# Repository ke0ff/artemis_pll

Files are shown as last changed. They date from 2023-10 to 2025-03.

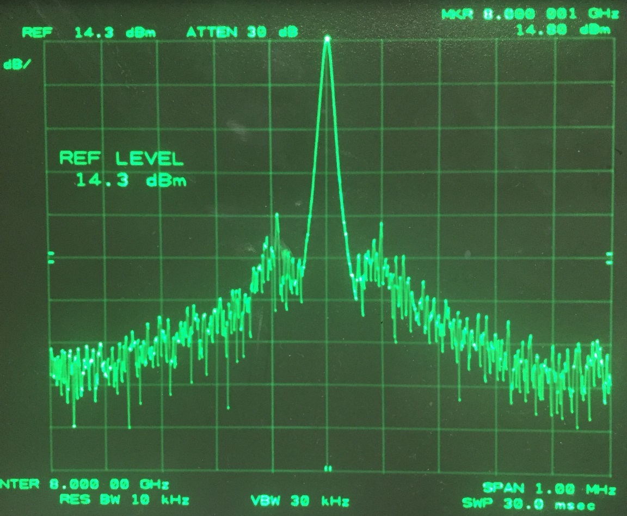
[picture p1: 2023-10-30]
Artemis_8GHz.JPG

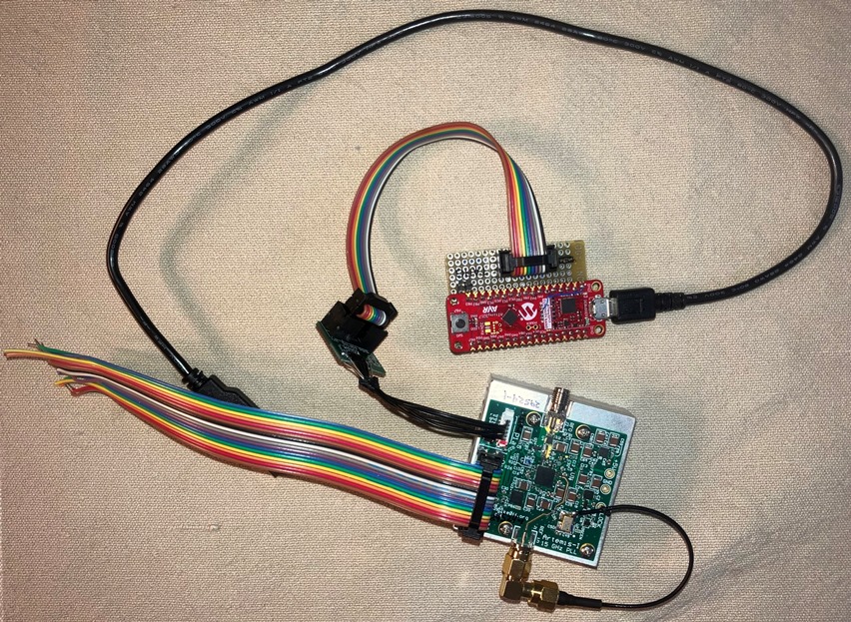
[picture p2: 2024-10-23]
Artemis with pgmr.JPG

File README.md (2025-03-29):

# artemis_pll
LMX2594 PLL Synth Project Files (4 GHz to 15 GHz)

Artemis PLL Synthesizer application

The follow-on to the Orion synthesizer.  Artemis uses an LMX2594 (TI) PLL (with integrated VCO) and an ATtiny-3217 to configure the PLL via an SPI interface. Uses a 5-bit channel select logic interface to set a channel (32 max channels, but likely just a handful will be implemented) or can accept serial commands (115200 baud) to set channel using a serial command line format. Currently requires channel data to be previously determined using the TI application software (TICS Pro) and compiled using the Microchip/Atmel code development environment.
Note: While the TI LMX2594 covers 10MHz to 15 GHz, the choice of buffer amplifier limits the available output range to 4 GHz and above.  For applications needing less than 4GHz, use the Orion-I synthesizer.  For applications needing full coverage, a different amplifier design would be needed -- This would likely mean removing/bypassing the existing buffer (not a good idea at RF) or produce a different PCB layout.

Atemis3217.zip holds the initial software project commit as a single zip archive.
Artemis Source holds in-process commits (files changed as individual source files).

Software for this project was developed with the AtmelStudio IDE.  Microchip has rebranded this as the MicrochipStudio For AVR devices.  Visit https://www.microchip.com/en-us/tools-resources/develop/microchip-studio to install the current version of this toolchain.  To Build the SW project, first unzip "Artemis3217.zip".  Next, copy files (if any) from "Artemis Source" to their respective locations inside the Atmel project folder structure (this might require some trial and error to find where the files belong).
Lastly, build the project and program the target device.  Note: if the "Artemis Source" folder is empty, there are no files to copy.

See my Programming Guide (https://ke0ff.github.io/Orion/silabspgm.pdf) for details on how to build a UPDI programmer using a CurosityNano-3217 development board.

TICSPro software (https://www.ti.com/tool/TICSPRO-SW) from TI is the best choice for configuring the PLL and capturing the resulting register settings (there are 112, 16b registers, 79 of which are required for basic Artemis operation).

These supporting files are also included:</br>
ArtemisHW.zip holds the CircuitStudio schematic and PCB files</br>
Artemis_schem.pdf is the schematic in pdf format</br>
Artemis_BOM.xlsx is the Bill Of Materials</br>

V0.3 SW is now in alpha-test:</br>
Features 8 channels with download and FLASH programming capability to allow stand-alone channel maintenance.  Temporary download channel can be sent to PLL for test, or programmed to a FLASH channel.

Temperature sensor calibration is now in User EEPROM allowing stand-alone calibraton that is not disturbed by programming operations.

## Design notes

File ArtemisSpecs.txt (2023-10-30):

Specifications for Artemis-I, 4 GHz - 15 GHz synthesizer
Preliminary, 10/29/2023
Designed by: Joe Haas, KE0FF

PLL: TI LMX2594HAT, 10 MHz - 15 GHz PLL, on-board lock LED indicator
Buffer: PMA2-183LN+, 4-18 GHz, +14dBm IP1
DC Power: +5Vdc, 400mA
	NOTE: Board requires a heatshink/thermal pad solution
REF: Solder-selectable jumper/capacitor
	EXT REF connection: SMA, 0.2 - 2.0 Vpp, 5 MHz (min) - 1400 MHz (max)
	INT REF: 25MHz, EXC-TX053-S3-33-250-BN-TR
TTL UART cmd I/O: 3.3V logic, 115200 baud, n81
Control MCU: ATTINY-3217 (uses Atmel 1-wire UPDI programming connection)

RF Out (preliminary), SMA:
4GHz	+14dBm
8GHz	+14dBm	phase noise = -80 dBm/Hz
11GHz	+12dBm
13GHz	+10dBm
PLL programming allows for adjustment of the output level in 32 steps.
The data above depicts the maximum setting for each frequency listed

Physical:
Board dimensions: 1.740" x 1.875" x 0.355" (excluding SMA & P2 connectors)
MTG holes, #2 DIA, 4 places
P2 pinout
 1: +12Vin (not used)
 2: GND
 3: Debug RXD, 3.3V TTL serial, input to Artemis board
 4: +5V in
 5: Bebug TXD, 3.3V TTL serial, output from Artemis board
 6: GND
 7: /DISABLE (GND = disable output)
 8: FSEL0
 9: FSEL1
10: FSEL2
11: FSEL3
12: FSEL4
13: N/C
14: UPDI programming connection for ATTINY MCU
15: +3.3V output (10 mA, max)
16: GND

FSEL[4:0] form the channel selection vector allowing up to 32 different
frequency selections from a single master PLL register suite.

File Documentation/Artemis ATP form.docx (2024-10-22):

Artemis Acceptance Test Procedure

Date: _____ / ______ / 20___ S/N: ___________________ SW Version: _______

Test Operator: ______________ Power +5Vin: _______________ Vdc (measure at PCB TP)

1) UART TX serial test: Observe Power-on banner message. Passes if message is displayed with no garbled characters. P/F: _________

2) UART RX serial test: Issue “?” help command from PC terminal. Passes if help message is displayed with no garbled characters. P/F: _________

3) FSEL Test: Cycle through binary inputs and observe channel display on serial terminal. Passes if all digits are recognized and displayed (after settling). P/F: _________

4) /MUTE Test: cycle /MUTE, and observe channel display on serial terminal. Passes if channel output toggles (muted output less or equal to -40 dBc when unmuted) P/F: _________

5) +3.3V out Test: Measure P2-15 with a DMM. Passes if voltage = 3.3V ±10%.

V(3.3V): ____________ P/F: _________

6) Sideband Test: Set CH2 and observe the output at 11 GHz on a spectrum analyzer (1 MHz span). Verify that any sidebands are ≤-40 dBc. Record strongest sideband. Note: sidebands are considered measurable if they are greater than 3 dB above the noise floor.

(Fc level: ________ dBm) – (SB level: _______ dBm) = _________ dBc

Span: ___________ MHz SB Frequency: Fc± ___________ (MHz) P/F: _________

7) Output level test #1: Set CH1 and observe the output at 8 GHz on a spectrum analyzer. Record the signal level. Passes if output is ≥ +10 dBm & frequency is 8 GHz +/-10KHz.

Level: __________ dBm P/F: _________

8) Output level test #2: Set CH3 and observe the output at 15 GHz on a spectrum analyzer. Record the signal level. Passes if output is ≥ 0 dBm. Level: __________ dBm P/F: _________

Set CH0, passes if 3 GHz level is ≥ +10 dBm Level: __________ dBm P/F: _________

9) Noise Test: Set CH2 and observe the output at 11 GHz on a spectrum analyzer. Center on the peak, set a 100 Khz span and measure the abs. noise level. Passes if NL is better than -78 dBc/Hz at 10KHz offset. Fc level: __________ dBm Noise level: ______________ dBm/Hz

NL (dBc) = {Noise Level} - {Fc level} = ______________ dBc/Hz P/F: _________

10) Load custom channel config and test with custom reference settings. Done: ________

REFERENCE Freq: __________________ Level: ___________________

FSEL 0: ___________________________ FSEL 1: ___________________________

FSEL 2: ___________________________ FSEL 3: ___________________________

Test Operator Signature: ___________________________________________

REV - 10/21/2024

Artemis ATP: Test Setup

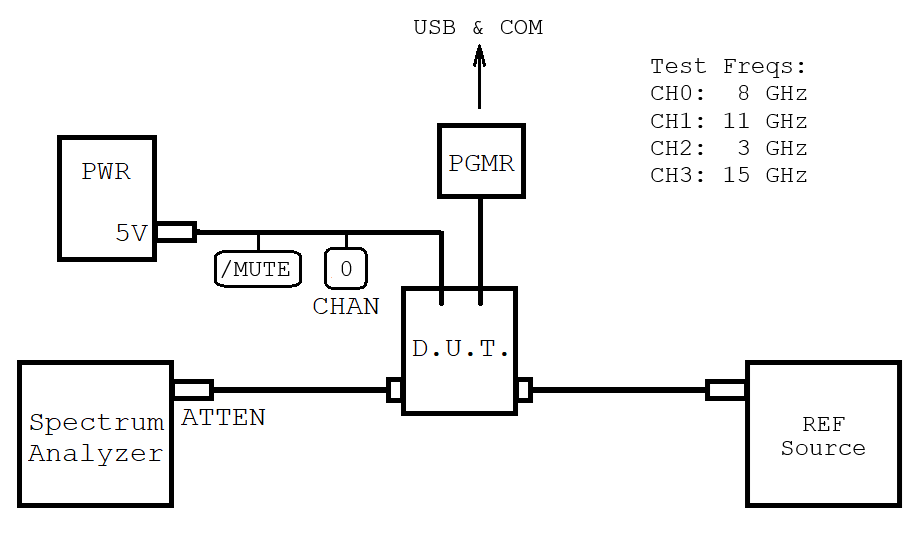
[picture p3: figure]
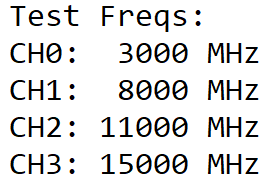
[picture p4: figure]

POWER SUPPLY: ______________________________________________

DMM Model/SN: _______________________________________________

S/A: __________________________________________________________

EXT. ATTEN: ______ dB ATTEN MODEL/SN: ______________________________

D.U.T. RF OUT CABLE: _________________________________________

LOSS AT 2 GHz: ________________ dB LOSS AT 12 GHz: _______________ dB

LOSS AT 8 GHz: _______________ dB LOSS AT 15 GHz: _______________ dB

ATP REF SOURCE: ______________________________________________

LEVEL AT D.U.T. CONNECTOR: ________________ dBm

Date: _____ / ______ / 20___ TEST OPERATOR: ________________________________

REV - 10/21/2024

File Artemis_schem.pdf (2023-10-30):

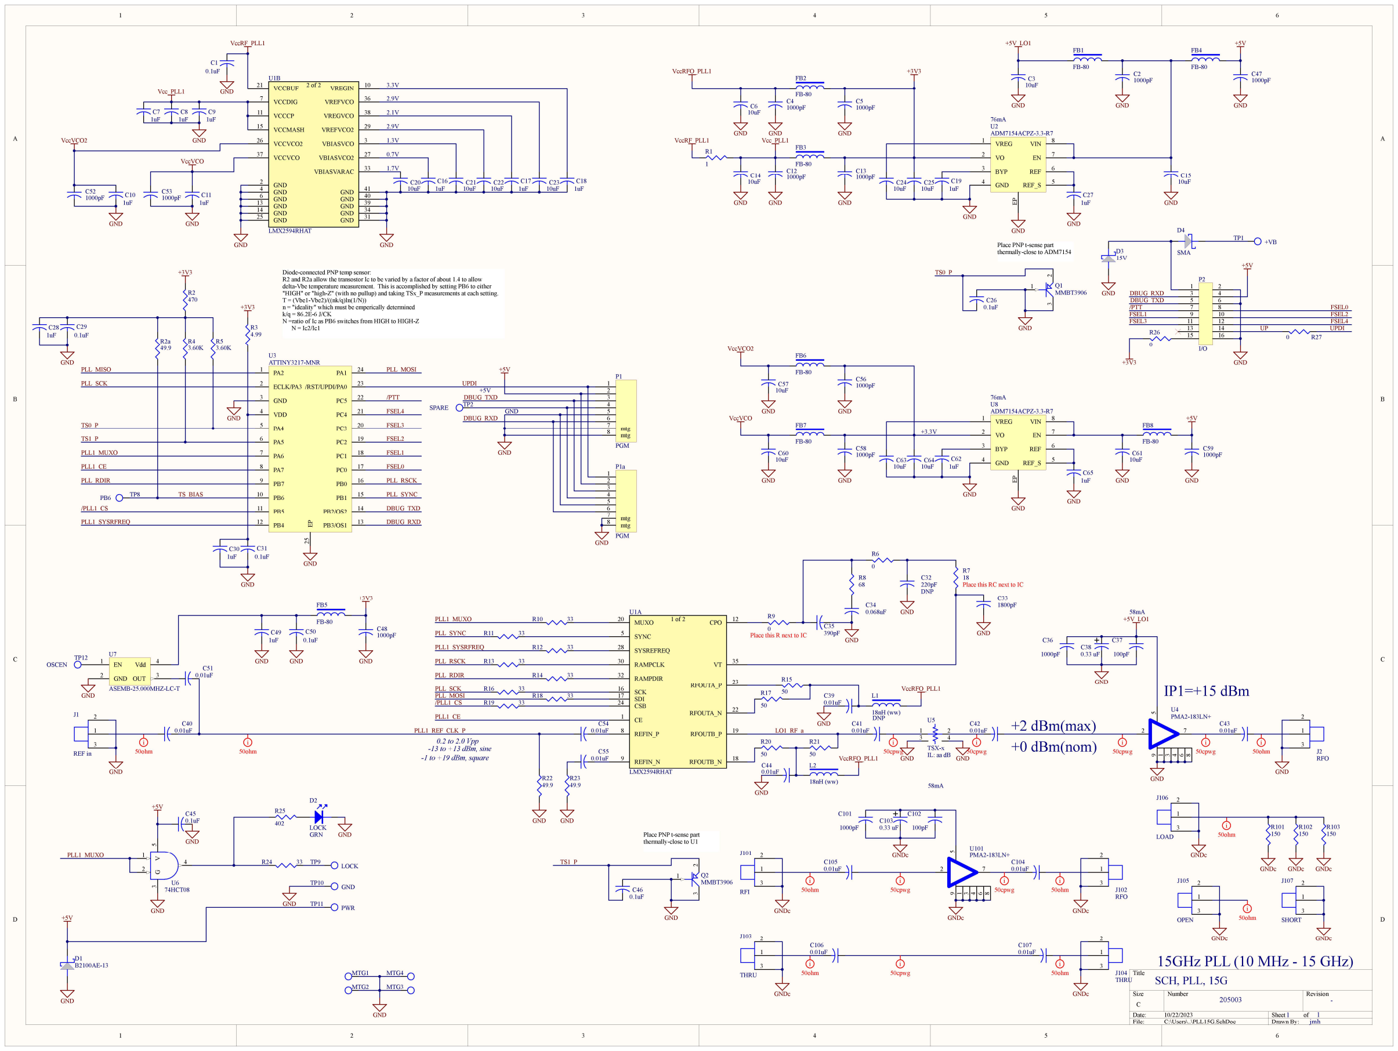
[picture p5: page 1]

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
Title

Size | Number | | Revision
C
Date: | 10/22/2023 | Sheet | of
File: | C:\Users\..\PLL15G.SchDoc | Drawn By:

| | | 1 1

# SCH, PLL, 15G

205003

jmh

VREG 1

VO 2

BYP 3

GND 4 | REF_S | 5
| REF | 6
| EN | 7
VIN | 8 EP

U2
ADM7154ACPZ-3.3-R7

C19
1uF

C25
10uF

C24
10uF
C27
1uF

GND

GND

GND

C13
1000pF

GND

C15
10uF

FB3

FB-80
C12
1000pF

GND

C14
10uF

GND

PLL1_MUXO

PLL1_CE

PLL_MOSI

PLL_SCK

/PLL1_CS

C35
390pF

68

R8 | 18 R7

C34
0.068uF

DNP

C32
220pF

C33
1800pF

GND

GND

Place this R next to IC | GND Place this RC next to IC
R16 | 33
R19 | 33
R18 | 33

49.9

R23

GND

1

R1

Vcc_PLL1

VccRF_PLL1

R10 | 33

0

R6

0

R9

CE 1

CPO | 12
VT | 35

SCK 16
SDI 17
CSB 24

MUXO 20

RFOUTB_N | 18
RFOUTB_P | 19
RFOUTA_P | 23

### 1 of 2

RFOUTA_N 22

SYNC 5

SYSREFREQ 28

RAMPCLK 30

RAMPDIR 32

REFIN_N 9

REFIN_P 8

U1A

LMX2594RHAT

VCCBUF 21

VCCDIG 7

VCCCP 11

VCCMASH 15

VCCVCO2 26

VCCVCO 37

GND 4
GND 6
GND 13
GND 14
GND 25 | GND | 31 GND | 34 GND | 39 GND | 40 GND | 41

### 2 of 2

GND 2

VREGIN | 10
VREFVCO | 36
VREGVCO | 38
VREFVCO2 | 29
VBIASVCO | 3
VBIASVCO2 | 27
VBIASVARAC | 33

U1B

LMX2594RHAT

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
10uF

C21
10uF

C17
1uF

C22
10uF

C18
1uF

C23
10uF

GND

VccRF_PLL1 | Vcc_PLL1

GND

C1
0.1uF

PLL1_REF_CLK_P

### 0.2 to 2.0 Vpp -13 to +13 dBm, sine

50

R21

C41
0.01uF

L2

18nH (ww)

50

R20

C44
0.01uF

GND

C5
1000pF

GND

FB2

FB-80
C4
1000pF

GND

C6
10uF

GND

VccRFO_PLL1

VccRFO_PLL1

50

R15

DNP

L1

18nH (ww)

50

R17 | C39 0.01uF
| GND

VccRFO_PLL1

PLL1_SYSRFREQ

PLL_SYNC | R11 | 33
R12 | 33

PLL_RDIR

PLL_RSCK | R13 | 33
R14 | 33

C2
1000pF

GND

FB1

FB-80
C3
10uF

GND

+5V_LO1

# 15GHz PLL (10 MHz - 15 GHz)

### -1 to +19 dBm, square

LO1_RF_a

GND

C37

100pF

GND

58mA
+5V_LO1

C36

1000pF

C38

### 0.33 uF

76mA

i
50cpwg

i
50cpwg

# +2 dBm(max)

# IP1=+15 dBm

2

1

3
J2
RFO

D1
B2100AE-13

2 7 ⁵ 9

1

3

4

6

8

U4
PMA2-183LN+

# +0 dBm(nom)

VDD 4

PA4 5

PA5 6

PA6 7

PA7 8

PB7 9

PB6 10

PB3/OS1 | 13
PB2/OS2 | 14
PB1 | 15

GND 3

ECLK/PA3 2

PA2 1 | PA1 | 24
| /RST/UPDI/PA0 | 23
PC3 | 20
PC2 | 19
PC1 | 18
PC0 | 17
PB0 | 16 EP 25

PB5 11

PB4 12

PC4 | 21
PC5 | 22

U3
ATTINY3217-MNR

1 2

IL: aa dB

3 4

U5

TSX-x
GND | GND

C43
0.01uF

C42
0.01uF

+3V3

+3V3

C30
1uF

C31
0.1uF

GND

4.99

R3

GND

PLL1_MUXO

PLL1_CE

PLL_MOSI

PLL_SCK

/PLL1_CS

PLL1_SYSRFREQ

PLL_SYNC

PLL_RDIR | PLL_RSCK

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
mtg 7
mtg 8

P1

PGM

+5V

DBUG_TXD

DBUG_RXD

PLL_MISO

TS0_P

TS1_P

C46
0.1uF

1 2 3
Q2
MMBT3906

GND

Place PNP t-sense part
thermally-close to U1

TS1_P

3.60K

R5

GND

470

R2

3.60K

R4

+3V3

C28
1uF

C29
0.1uF

GND

C26
0.1uF

1 2 3
Q1
MMBT3906

GND

Place PNP t-sense part
thermally-close to ADM7154

TS0_P

TP8 PB6

2

1

3

J1

REF in

C40
0.01uF

49.9

R22

GND

GND | GND
GND | GND

i
50ohm

i
50ohm

i
50ohm

i
50cpwg

i
50cpwg
TP11 | PWR
TP10 | GND
TP9 | LOCK

PLL1_MUXO

GND

1

2

### 4 V

### 5 G

3

U6
74HCT08
R24 | 33

GND

1.7V

0.7V

1.3V

2.9V

2.1V

2.9V

3.3V

+5V

GND

+5V

GND

+5V
C45
0.1uF

GND

TP2 SPARE

C47
1000pF

GND

FB4

FB-80

EN 1

GND 2 | OUT | 3
| Vdd | 4

U7

ASEMB-25.000MHZ-LC-T
GND

TP12
OSCEN | C51 0.01uF

C48
1000pF

GND

FB5

FB-80

GND | GND

C49
1uF

C50
0.1uF

+3V3

VREG 1

VO 2

BYP 3

GND 4 | REF_S | 5
| REF | 6
| EN | 7
VIN | 8 EP

U8
ADM7154ACPZ-3.3-R7

C62
1uF

C64
10uF

C63
10uF
C65
1uF

GND

GND

GND

C58
1000pF

GND

C61
10uF

FB7

FB-80
C60
10uF

GND

VccVCO

C56
1000pF

GND

FB6

FB-80
C57
10uF

GND

VccVCO2

76mA

+5V

GND

C59
1000pF

GND

FB8

FB-80

C11
1uF

GND

C10
1uF

GND

C53
1000pF

C52
1000pF

VccVCO

VccVCO2

+3.3V

402

R25

GRN

D2

LOCK
GND

DBUG_TXD

DBUG_RXD

UPDI

1
2
3
4
5
6
mtg 7
mtg 8

P1a

PGM
GND

MTG3

GND

MTG4

MTG2

MTG1

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
/PTT
FSEL1
FSEL3

FSEL0
FSEL2

GND

+5V

FSEL1

FSEL3

FSEL0

FSEL2

D3
15V

GND

D4

SMA

TP1
+VB

DBUG_TXD

DBUG_RXD

+3V3

FSEL4

0

R26

/PTT

FSEL4

C54
0.01uF

C55
0.01uF

2

1

3

J101

RFI

GNDc

i
50ohm

2

1

3
J102
RFO

C104

2 | 7 | 0.01uF ⁵ 9

1

3

4

6

8

U101
PMA2-183LN+

i
50ohm

C102

100pF

58mA

C101

1000pF

C103

### 0.33 uF

GNDc

GNDc
GNDc

i
50cpwg

2

1

3

J103

THRU

GNDc

i
50ohm

2

1

3
J104
THRU

C107
0.01uF
i
50ohm

GNDc

i
50cpwg

C105
0.01uF

C106
0.01uF

i
50cpwg

2

1

3

J105

OPEN

GNDc

i
50ohm

2

1

3

J107

SHORT

GNDc

2

1

3

J106

LOAD

GNDc

i
50ohm

GNDc

150

R101

GNDc

150

R102

GNDc

150

R103

UPDI

### 0 R27

UP

49.9

R2a

Diode-connected PNP temp sensor:
R2 and R2a allow the transostor Ic to be varied by a factor of about 1.4 to allow delta-Vbe temperature measurement. This is accomplished by setting PB6 to either "HIGH" or "high-Z" (with no pullup) and taking TSx_P measurements at each setting. T = (Vbe1-Vbe2)/((nk/q)ln(1/N))
n = "ideality" which must be emperically determined
k/q = 86.2E-6 J/CK
N =ratio of Ic as PB6 switches from HIGH to HIGH-Z N = Ic2/Ic1

TS_BIAS

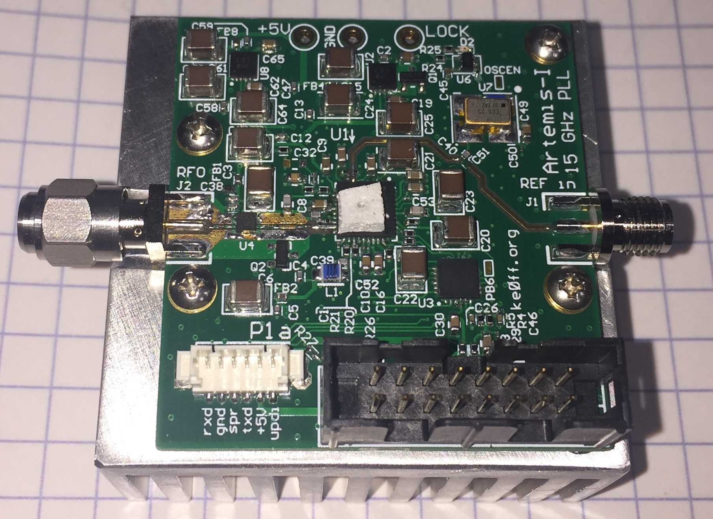
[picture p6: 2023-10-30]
Artemis-I.JPG

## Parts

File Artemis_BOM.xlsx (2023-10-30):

Qty | Designator | Description | MFR | MPN | Cost | Cost ea.
4 | C1, C29, C31, C50 | CAP, MLCC, X5R, 0201, 25V, 10%, 0.1uF | Taiyo Yuden | GMK063BJ104KP-F | $0.20 | 0.050
10 | C2, C4, C5, C12, C13, C47, C48, C56, C58, C59 | CAP, MLCC, C0G, 0402, 100V, 10%, 1000pF | Kemet | C0402C102J1GEC7411 | $0.59 | 0.059
3 | C26, C45, C46 | CAP, MLCC, X5R, 0402, 25V, 10%, 0.1uF | Murata | GRM155R71H104KE14D | $0.04 | 0.014
2 | C27, C65 | CAP, MLCC, X7R, 0603, 50V, 10%, 1uF | Taiyo Yuden | UMK107AB7105MA-T | $0.37 | 0.186
15 | C3, C6, C14, C15, C20, C21, C22, C23, C24, C25, C57, C60, C61, C63, C64 | CAP, MLCC, X7R, 1210, 50V, 10%, 10uF | Kemet | C1210C106K5RACTU | $7.98 | 0.532
1 | C33 | CAP, MLCC, C0G, 0603, 100V, 10%, 1800pF | Murata | GRM1885C2A182JA01D | $0.04 | 0.038
1 | C34 | CAP, MLCC, C0G, 0603, 50V, 10%, 0.068uF | TDK | VJ0603Y683KXACW1BC | $0.03 | 0.028
1 | C35 | CAP, MLCC, C0G, 0603, 50V, 10%, 390pF | TDK | C1608C0G2A391K080AA | $0.04 | 0.045
1 | C36 | CAP, MLCC, C0G, 0402, 50V, 5%, 1000pF | Murata | GRM1555C1H102FA01D | $0.07 | 0.066
1 | C37 | CAP, MLCC, C0G, 0402, 50V, 5%, 100pF | Murata | GRM1555C1H101JA01J | $0.01 | 0.013
1 | C38 | CAP, TANT, SMD, 0402, 0.33uF, 20V | ROHM Semi | TCTU1D334M8R | $0.33 | 0.331
3 | C39, C44, C51 | CAP, MLCC, C0G, 0402, 16V, 10%, 10000pF | Murata | GRM1555CYA103GE01D | $0.20 | 0.068
3 | C41, C42, C43 | CAP, MLCC, C0G, 0201, 16V, 10%, 0.1uF | Passives Plus | 0201BB104KW160 | $3.71 | 1.236
2 | C54, C55 | CAP, MLCC, C0G, 0201, 16V, 10%, 10000pF | Taiyo Yuden | MSASU063SB5103KFNA01 | $0.14 | 0.071
2 | C52, C53 | CAP, MLCC, C0G, 0201, 100V, 10%, 1000pF | Murata | GRM0335C1H102GE01D | $0.04 | 0.019
13 | C7, C8, C9, C10, C11, C16, C17, C18, C19, C28, C30, C49, C62 | CAP, MLCC, X7R, 0603, 50V, 10%, 1uF | Taiyo Yuden | MSASU168AB7105KTNA01 | $2.27 | 0.175
1 | D1 | DIO, 50V, SHTKY, SMA | MCC | SS2150-LTP | $0.27 | 0.273
1 | D2 | LED, 0402, GRN | Kingbright | APG1005CGC-T | $0.24 | 0.240
1 | D3 | DIO, TVS, 15V, 500W | MCC | SMAJ16A-TP | $0.27 | 0.267
1 | D4 | DIO, TVS, 5V, 500W, DIODE | Yageo | P4SMA6.8A/TR13 | $0.26 | 0.260
8 | FB1, FB2, FB3, FB4, FB5, FB6, FB7, FB8 | Bead, Ferrite, SMD, 80 ohm | Laird | MI0402K121R-10 | $0.98 | 0.123
2 | J1, J2 | CONN, SMA, EDGE | TE Connectivity | CONSMA003.062 | $8.70 | 4.350
2 | L1, L2 | IND, CHP, WW, 3.3nH, 0805 | Kyocera | L08053R3CEWTR | $1.41 | 0.707
0 | P1 or P1a | CON, PICBLD, 1.25MM, 6POS (optional) | Molex | 53398-0671 | $0.00 | 0.715
1 | P2 | CON, DIP, 16 POS | 3M | D2516-6002-AR | $2.02 | 2.020
1 | P2-mate | CON, IDC, 16 POS | 3M | D89116-0031HK | $1.74 | 1.740
6 | P2-cable (per inch) | CBL, RBN, 16 POS | 3M | 3801/16 | $0.40 | 0.067
2 | Q1, Q2 | TRAN, PNP, 40V, 100mA, 4.7K bias | OnSemi | MMUN2132LT1G | $0.18 | 0.091
1 | R1 | RES, CHP, 0402, 1%, 100ppm/C, 1 | Vishay/Dale | RCC04021R00FKED | $0.05 | 0.048
9 | R10, R11, R12, R13, R14, R16, R18, R19, R24 | RES, CHP, 0402, 1%, 33 | Yageo | RC0402FR-0733RL | $0.08 | 0.009
2 | R15, R17 | RES, CHP, RF, 0402, 0.1%, 50 | Vishay/Dale | FC0402E50R0BST1 | $4.34 | 2.170
1 | R2 | RES, CHP, 0402, 1%, 470 | Yageo | RC0402FR-07470RL | $0.01 | 0.009
4 | R20, R21, R22, R23 | RES, CHP, 0201, 1%, 49.9 | Yageo | RC0201FR-0749R9L | $0.04 | 0.009
1 | R25 | RES, CHP, 0402, 1%, 402 | Yageo | RC0402FR-07402RL | $0.01 | 0.009
1 | R2a | RES, CHP, 0402, 1%, 49.9 | Yageo | RC0402FR-0749R9L | $0.01 | 0.009
1 | R3 | RES, CHP, 0402, 1%, 4.99 | Yageo | RC0402FR-074R99L | $0.01 | 0.009
2 | R4, R5 | RES, CHP, 0402, 1%, 3.60K | Yageo | RC0402FR-073K6L | $0.02 | 0.009
4 | R6, R9, R26, R27 | RES, CHP, 0402, 1%, 0 | Yageo | RC0402FR-070RL | $0.04 | 0.009
1 | R7 | RES, CHP, 0402, 1%, 18 | Yageo | RC0402FR-0718RL | $0.01 | 0.009
1 | R8 | RES, CHP, 0402, 1%, 68 | Yageo | RC0402FR-0768RL | $0.01 | 0.009
1 | U1 | IC, PLL, w/VCO, 7.3-15000 MHz, 300MHz REF | TI | LMX2594RHAT | $84.21 | 84.210
2 | U2, U8 | IC, VREG, ULN, 3.3V | Analog Devices | ADM7154ACPZ-3.3-R7 | $13.92 | 6.960
1 | U3 | IC, MCU, SFF, 8b, 32Kb, 20MHz | MicroChip | ATTINY3217-MNR | $1.25 | 1.250
1 | U4 | MMIC, AMP, E-PHEMT | Mini Circuits | PMA2-183LN+ | $38.98 | 38.980
1 | U6 | IC,GATE,2IN,AND,SNGL, | TI | SN74AHC1G08DCKR | $0.24 | 0.245
ALT | U7 | IC, OSC, SMD, W_EN | Abracon | ASEMB-25.000MHZ-LC-T |  | 2.840
1 | U7 | IC, OSC, SMD, W_EN | ECS | ECS-TXO53-S3-33-250-BN-TR | $9.86 | 9.860
1 | PCB | PCB, Artemis-I, Rev - | ANY | Artemis-I | $12.00 | 12.000
1 | THP1 | Pad, Thermal, 1”x1” | Laird | A15959-07 | $0.76 | 0.762
1 | HS1 | Heat Sink, 2”x2”, 5W – heatsinkonline.com | heatsinkonline.com | 253AS | $2.68 | 2.680
1 | MACHINE-OP | Machining for HS1, LOT | ANY | PER-DWG | $20.00 | 20.000
1 | PCB-ASSY | ASSEMBLY COSTS, PCB | ANY | PER-DWG | $20.00 | 20.000
1 | MISC | MISC FREIGHT COSTS/TAXES | N/A |  | $25.24 | 25.239
 |  |  |  |  | ==========
 |  |  |  | Total cost => | $266.31
DO NOT POPULATE:
1 | C32 | CAP, MLCC, C0G, 0402, ?V, 10%, ?pF | ? | ?
1 | C40 | CAP, MLCC, C0G, 0402, 16V, 10%, 10000pF | Murata | GRM1555CYA103GE01D
1 | U5 | ATTEN, FXD, SMD, 1W | Smiths Interconnect | TSXaa.00

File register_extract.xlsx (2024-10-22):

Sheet: Output
Artemis Channel Formatting Spreadsheet
Copy data from TICSPro export files into the respective channel tabs. Copy and paste all of the file data.
Be sure to align the pasted data to cell A1 in each channel tab.
Once all of the channels are configured, copy the “A” and “B” columns into the “channels.c” source file in the ATTINY project
Compile and load the program onto the Artemis board.
Note: All channels need to have valid data even if they are not going to be used.
{ | // channel 0 | <<== Copy from here to the last row
0x0180,
0x0003,
0x0000,
0x000C,
0x0800,
0x0000,
0x003F,
0x0001,
0x0081,
0xC350,
0x0000,
0x03E8,
0x0000,
0x01F4,
0x0000,
0x1388,
0x0000,
0x0322,
0x00A8,
0x0000,
0x0001,
0x9001,
0x0020,
0x0000,
0x0000,
0x0000,
0x0000,
0x0820,
0x0080,
0x0000,
0x4180,
0x0300,
0x0300,
0x07FC,
0xC0DF,
0x1FA3,
0x0000,
0x0000,
0x0000,
0x0000,
0x03E8,
0x0000,
0x0404,
0x0240,
0x0004,
0x0000,
0x1E21,
0x0393,
0x43EC,
0x318C,
0x318C,
0x0488,
0x0002,
0x0DB0,
0x0C2B,
0x071A,
0x007C,
0x0001,
0x0401,
0xE048,
0x27B7,
0x0064,
0x012C,
0x0080,
0x064F,
0x1E70,
0x4000,
0x5001,
0x0018,
0x10D8,
0x1604,
0x2000,
0x40B2,
0xC802,
0x00C8,
0x0A43,
0x0642,
0x0500,
0x0808,
0x241C
},
{ | // channel 1
0x0180,
0x0003,
0x0000,
0x000C,
0x0800,
0x0000,
0x003F,
0x0001,
0x0081,
0xC350,
0x0000,
0x03E8,
0x0000,
0x01F4,
0x0000,
0x1388,
0x0000,
0x0322,
0x00A8,
0x0000,
0x0001,
0x9001,
0x0020,
0x0000,
0x0000,
0x0000,
0x0000,
0x0820,
0x0080,
0x0000,
0x4180,
0x0300,
0x0300,
0x07FC,
0xC0DF,
0x1FA3,
0x0000,
0x0000,
0x0000,
0x0000,
0x03E8,
0x0000,
0x0404,
0x0240,
0x0004,
0x0000,
0x1E21,
0x0393,
0x43EC,
0x318C,
0x318C,
0x0488,
0x0002,
0x0DB0,
0x0C2B,
0x071A,
0x007C,
0x0001,
0x0401,
0xE048,
0x27B7,
0x0064,
0x012C,
0x0080,
0x064F,
0x1E70,
0x4000,
0x5001,
0x0018,
0x10D8,
0x1604,
0x2000,
0x40B2,
0xC802,
0x00C8,
0x0A43,
0x0642,
0x0500,
0x0808,
0x241C
},
{ | // channel 2
0x0180,
0x0003,
0x0000,
0x000C,
0x0800,
0x0000,
0x003F,
0x0001,
0x0081,
0xC350,
0x0000,
0x03E8,
0x0000,
0x01F4,
0x0000,
0x1388,
0x0000,
0x0322,
0x00A8,
0x0000,
0x0001,
0x9001,
0x0020,
0x0000,
0x0000,
0x0000,
0x0000,
0x0820,
0x0080,
0x0000,
0x4180,
0x0300,
0x0300,
0x07FC,
0xC0DF,
0x1FA3,
0x0000,
0x0000,
0x0000,
0x0000,
0x03E8,
0x0000,
0x0404,
0x0240,
0x0004,
0x0000,
0x1E21,
0x0393,
0x43EC,
0x318C,
0x318C,
0x0488,
0x0002,
0x0DB0,
0x0C2B,
0x071A,
0x007C,
0x0001,
0x0401,
0xE048,
0x27B7,
0x0064,
0x012C,
0x0080,
0x064F,
0x1E70,
0x4000,
0x5001,
0x0018,
0x10D8,
0x1604,
0x2000,
0x40B2,
0xC802,
0x00C8,
0x0A43,
0x0642,
0x0500,
0x0808,
0x241C
},
{ | // channel 3
0x0180,
0x0003,
0x0000,
0x000C,
0x0800,
0x0000,
0x003F,
0x0001,
0x0081,
0xC350,
0x0000,
0x03E8,
0x0000,
0x01F4,
0x0000,
0x1388,
0x0000,
0x0322,
0x00A8,
0x0000,
0x0001,
0x9001,
0x0020,
0x0000,
0x0000,
0x0000,
0x0000,
0x0820,
0x0080,
0x0000,
0x4180,
0x0300,
0x0300,
0x07FC,
0xC0DF,
0x1FA3,
0x0000,
0x0000,
0x0000,
0x0000,
0x03E8,
0x0000,
0x0404,
0x0240,
0x0004,
0x0000,
0x1E21,
0x0393,
0x43EC,
0x318C,
0x318C,
0x0488,
0x0002,
0x0DB0,
0x0C2B,
0x071A,
0x007C,
0x0001,
0x0401,
0xE048,
0x27B7,
0x0064,
0x012C,
0x0080,
0x064F,
0x1E70,
0x4000,
0x5001,
0x0018,
0x10D8,
0x1604,
0x2000,
0x40B2,
0xC802,
0x00C8,
0x0A43,
0x0642,
0x0500,
0x0808,
0x241C
}
}; |  | <<== This is the last row
///////////////////////////////////////////////////////////////////////////////////////////////////////

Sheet: CH_0
R112 | 0x700000 |  | <<== Insert channel data at cell A1
R111 | 0x6F0000
R110 | 0x6E0000
R109 | 0x6D0000
R108 | 0x6C0000
R107 | 0x6B0000
R106 | 0x6A0000
R105 | 0x690021
R104 | 0x680000
R103 | 0x670000
R102 | 0x663B00
R101 | 0x650011
R100 | 0x640000
R99 | 0x630000
R98 | 0x621400
R97 | 0x610888
R96 | 0x600000
R95 | 0x5F0000
R94 | 0x5E0000
R93 | 0x5D0000
R92 | 0x5C0000
R91 | 0x5B0000
R90 | 0x5A0000
R89 | 0x590000
R88 | 0x580000
R87 | 0x570000
R86 | 0x560001
R85 | 0x550000
R84 | 0x540001
R83 | 0x53FFFF
R82 | 0x52FFFF
R81 | 0x510000
R80 | 0x500000
R79 | 0x4F0180 | 0x0180,
R78 | 0x4E0003 | 0x0003,
R77 | 0x4D0000 | 0x0000,
R76 | 0x4C000C | 0x000C,
R75 | 0x4B0800 | 0x0800,
R74 | 0x4A0000 | 0x0000,
R73 | 0x49003F | 0x003F,
R72 | 0x480001 | 0x0001,
R71 | 0x470081 | 0x0081,
R70 | 0x46C350 | 0xC350,
R69 | 0x450000 | 0x0000,
R68 | 0x4403E8 | 0x03E8,
R67 | 0x430000 | 0x0000,
R66 | 0x4201F4 | 0x01F4,
R65 | 0x410000 | 0x0000,
R64 | 0x401388 | 0x1388,
R63 | 0x3F0000 | 0x0000,
R62 | 0x3E0322 | 0x0322,
R61 | 0x3D00A8 | 0x00A8,
R60 | 0x3C0000 | 0x0000,
R59 | 0x3B0001 | 0x0001,
R58 | 0x3A9001 | 0x9001,
R57 | 0x390020 | 0x0020,
R56 | 0x380000 | 0x0000,
R55 | 0x370000 | 0x0000,
R54 | 0x360000 | 0x0000,
R53 | 0x350000 | 0x0000,
R52 | 0x340820 | 0x0820,
R51 | 0x330080 | 0x0080,
R50 | 0x320000 | 0x0000,
R49 | 0x314180 | 0x4180,
R48 | 0x300300 | 0x0300,
R47 | 0x2F0300 | 0x0300,
R46 | 0x2E07FC | 0x07FC,
R45 | 0x2DC0DF | 0xC0DF,
R44 | 0x2C1FA3 | 0x1FA3,
R43 | 0x2B0000 | 0x0000,
R42 | 0x2A0000 | 0x0000,
R41 | 0x290000 | 0x0000,
R40 | 0x280000 | 0x0000,
R39 | 0x2703E8 | 0x03E8,
R38 | 0x260000 | 0x0000,
R37 | 0x250404 | 0x0404,
R36 | 0x240240 | 0x0240,
R35 | 0x230004 | 0x0004,
R34 | 0x220000 | 0x0000,
R33 | 0x211E21 | 0x1E21,
R32 | 0x200393 | 0x0393,
R31 | 0x1F43EC | 0x43EC,
R30 | 0x1E318C | 0x318C,
R29 | 0x1D318C | 0x318C,
R28 | 0x1C0488 | 0x0488,
R27 | 0x1B0002 | 0x0002,
R26 | 0x1A0DB0 | 0x0DB0,
R25 | 0x190C2B | 0x0C2B,
R24 | 0x18071A | 0x071A,
R23 | 0x17007C | 0x007C,
R22 | 0x160001 | 0x0001,
R21 | 0x150401 | 0x0401,
R20 | 0x14E048 | 0xE048,
R19 | 0x1327B7 | 0x27B7,
R18 | 0x120064 | 0x0064,
R17 | 0x11012C | 0x012C,
R16 | 0x100080 | 0x0080,
R15 | 0x0F064F | 0x064F,
R14 | 0x0E1E70 | 0x1E70,
R13 | 0x0D4000 | 0x4000,
R12 | 0x0C5001 | 0x5001,
R11 | 0x0B0018 | 0x0018,
R10 | 0x0A10D8 | 0x10D8,
R9 | 0x091604 | 0x1604,
R8 | 0x082000 | 0x2000,
R7 | 0x0740B2 | 0x40B2,
R6 | 0x06C802 | 0xC802,
R5 | 0x0500C8 | 0x00C8,
R4 | 0x040A43 | 0x0A43,
R3 | 0x030642 | 0x0642,
R2 | 0x020500 | 0x0500,
R1 | 0x010808 | 0x0808,
R0 | 0x00241C | 0x241C

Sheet: CH_1
R112 | 0x700000 |  | <<== Insert channel data at cell A1
R111 | 0x6F0000
R110 | 0x6E0000
R109 | 0x6D0000
R108 | 0x6C0000
R107 | 0x6B0000
R106 | 0x6A0000
R105 | 0x690021
R104 | 0x680000
R103 | 0x670000
R102 | 0x663B00
R101 | 0x650011
R100 | 0x640000
R99 | 0x630000
R98 | 0x621400
R97 | 0x610888
R96 | 0x600000
R95 | 0x5F0000
R94 | 0x5E0000
R93 | 0x5D0000
R92 | 0x5C0000
R91 | 0x5B0000
R90 | 0x5A0000
R89 | 0x590000
R88 | 0x580000
R87 | 0x570000
R86 | 0x560001
R85 | 0x550000
R84 | 0x540001
R83 | 0x53FFFF
R82 | 0x52FFFF
R81 | 0x510000
R80 | 0x500000
R79 | 0x4F0180 | 0x0180,
R78 | 0x4E0003 | 0x0003,
R77 | 0x4D0000 | 0x0000,
R76 | 0x4C000C | 0x000C,
R75 | 0x4B0800 | 0x0800,
R74 | 0x4A0000 | 0x0000,
R73 | 0x49003F | 0x003F,
R72 | 0x480001 | 0x0001,
R71 | 0x470081 | 0x0081,
R70 | 0x46C350 | 0xC350,
R69 | 0x450000 | 0x0000,
R68 | 0x4403E8 | 0x03E8,
R67 | 0x430000 | 0x0000,
R66 | 0x4201F4 | 0x01F4,
R65 | 0x410000 | 0x0000,
R64 | 0x401388 | 0x1388,
R63 | 0x3F0000 | 0x0000,
R62 | 0x3E0322 | 0x0322,
R61 | 0x3D00A8 | 0x00A8,
R60 | 0x3C0000 | 0x0000,
R59 | 0x3B0001 | 0x0001,
R58 | 0x3A9001 | 0x9001,
R57 | 0x390020 | 0x0020,
R56 | 0x380000 | 0x0000,
R55 | 0x370000 | 0x0000,
R54 | 0x360000 | 0x0000,
R53 | 0x350000 | 0x0000,
R52 | 0x340820 | 0x0820,
R51 | 0x330080 | 0x0080,
R50 | 0x320000 | 0x0000,
R49 | 0x314180 | 0x4180,
R48 | 0x300300 | 0x0300,
R47 | 0x2F0300 | 0x0300,
R46 | 0x2E07FC | 0x07FC,
R45 | 0x2DC0DF | 0xC0DF,
R44 | 0x2C1FA3 | 0x1FA3,
R43 | 0x2B0000 | 0x0000,
R42 | 0x2A0000 | 0x0000,
R41 | 0x290000 | 0x0000,
R40 | 0x280000 | 0x0000,
R39 | 0x2703E8 | 0x03E8,
R38 | 0x260000 | 0x0000,
R37 | 0x250404 | 0x0404,
R36 | 0x240240 | 0x0240,
R35 | 0x230004 | 0x0004,
R34 | 0x220000 | 0x0000,
R33 | 0x211E21 | 0x1E21,
R32 | 0x200393 | 0x0393,
R31 | 0x1F43EC | 0x43EC,
R30 | 0x1E318C | 0x318C,
R29 | 0x1D318C | 0x318C,
R28 | 0x1C0488 | 0x0488,
R27 | 0x1B0002 | 0x0002,
R26 | 0x1A0DB0 | 0x0DB0,
R25 | 0x190C2B | 0x0C2B,
R24 | 0x18071A | 0x071A,
R23 | 0x17007C | 0x007C,
R22 | 0x160001 | 0x0001,
R21 | 0x150401 | 0x0401,
R20 | 0x14E048 | 0xE048,
R19 | 0x1327B7 | 0x27B7,
R18 | 0x120064 | 0x0064,
R17 | 0x11012C | 0x012C,
R16 | 0x100080 | 0x0080,
R15 | 0x0F064F | 0x064F,
R14 | 0x0E1E70 | 0x1E70,
R13 | 0x0D4000 | 0x4000,
R12 | 0x0C5001 | 0x5001,
R11 | 0x0B0018 | 0x0018,
R10 | 0x0A10D8 | 0x10D8,
R9 | 0x091604 | 0x1604,
R8 | 0x082000 | 0x2000,
R7 | 0x0740B2 | 0x40B2,
R6 | 0x06C802 | 0xC802,
R5 | 0x0500C8 | 0x00C8,
R4 | 0x040A43 | 0x0A43,
R3 | 0x030642 | 0x0642,
R2 | 0x020500 | 0x0500,
R1 | 0x010808 | 0x0808,
R0 | 0x00241C | 0x241C

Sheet: CH_2
R112 | 0x700000 |  | <<== Insert channel data at cell A1
R111 | 0x6F0000
R110 | 0x6E0000
R109 | 0x6D0000
R108 | 0x6C0000
R107 | 0x6B0000
R106 | 0x6A0000
R105 | 0x690021
R104 | 0x680000
R103 | 0x670000
R102 | 0x663B00
R101 | 0x650011
R100 | 0x640000
R99 | 0x630000
R98 | 0x621400
R97 | 0x610888
R96 | 0x600000
R95 | 0x5F0000
R94 | 0x5E0000
R93 | 0x5D0000
R92 | 0x5C0000
R91 | 0x5B0000
R90 | 0x5A0000
R89 | 0x590000
R88 | 0x580000
R87 | 0x570000
R86 | 0x560001
R85 | 0x550000
R84 | 0x540001
R83 | 0x53FFFF
R82 | 0x52FFFF
R81 | 0x510000
R80 | 0x500000
R79 | 0x4F0180 | 0x0180,
R78 | 0x4E0003 | 0x0003,
R77 | 0x4D0000 | 0x0000,
R76 | 0x4C000C | 0x000C,
R75 | 0x4B0800 | 0x0800,
R74 | 0x4A0000 | 0x0000,
R73 | 0x49003F | 0x003F,
R72 | 0x480001 | 0x0001,
R71 | 0x470081 | 0x0081,
R70 | 0x46C350 | 0xC350,
R69 | 0x450000 | 0x0000,
R68 | 0x4403E8 | 0x03E8,
R67 | 0x430000 | 0x0000,
R66 | 0x4201F4 | 0x01F4,
R65 | 0x410000 | 0x0000,
R64 | 0x401388 | 0x1388,
R63 | 0x3F0000 | 0x0000,
R62 | 0x3E0322 | 0x0322,
R61 | 0x3D00A8 | 0x00A8,
R60 | 0x3C0000 | 0x0000,
R59 | 0x3B0001 | 0x0001,
R58 | 0x3A9001 | 0x9001,
R57 | 0x390020 | 0x0020,
R56 | 0x380000 | 0x0000,
R55 | 0x370000 | 0x0000,
R54 | 0x360000 | 0x0000,
R53 | 0x350000 | 0x0000,
R52 | 0x340820 | 0x0820,
R51 | 0x330080 | 0x0080,
R50 | 0x320000 | 0x0000,
R49 | 0x314180 | 0x4180,
R48 | 0x300300 | 0x0300,
R47 | 0x2F0300 | 0x0300,
R46 | 0x2E07FC | 0x07FC,
R45 | 0x2DC0DF | 0xC0DF,
R44 | 0x2C1FA3 | 0x1FA3,
R43 | 0x2B0000 | 0x0000,
R42 | 0x2A0000 | 0x0000,
R41 | 0x290000 | 0x0000,
R40 | 0x280000 | 0x0000,
R39 | 0x2703E8 | 0x03E8,
R38 | 0x260000 | 0x0000,
R37 | 0x250404 | 0x0404,
R36 | 0x240240 | 0x0240,
R35 | 0x230004 | 0x0004,
R34 | 0x220000 | 0x0000,
R33 | 0x211E21 | 0x1E21,
R32 | 0x200393 | 0x0393,
R31 | 0x1F43EC | 0x43EC,
R30 | 0x1E318C | 0x318C,
R29 | 0x1D318C | 0x318C,
R28 | 0x1C0488 | 0x0488,
R27 | 0x1B0002 | 0x0002,
R26 | 0x1A0DB0 | 0x0DB0,
R25 | 0x190C2B | 0x0C2B,
R24 | 0x18071A | 0x071A,
R23 | 0x17007C | 0x007C,
R22 | 0x160001 | 0x0001,
R21 | 0x150401 | 0x0401,
R20 | 0x14E048 | 0xE048,
R19 | 0x1327B7 | 0x27B7,
R18 | 0x120064 | 0x0064,
R17 | 0x11012C | 0x012C,
R16 | 0x100080 | 0x0080,
R15 | 0x0F064F | 0x064F,
R14 | 0x0E1E70 | 0x1E70,
R13 | 0x0D4000 | 0x4000,
R12 | 0x0C5001 | 0x5001,
R11 | 0x0B0018 | 0x0018,
R10 | 0x0A10D8 | 0x10D8,
R9 | 0x091604 | 0x1604,
R8 | 0x082000 | 0x2000,
R7 | 0x0740B2 | 0x40B2,
R6 | 0x06C802 | 0xC802,
R5 | 0x0500C8 | 0x00C8,
R4 | 0x040A43 | 0x0A43,
R3 | 0x030642 | 0x0642,
R2 | 0x020500 | 0x0500,
R1 | 0x010808 | 0x0808,
R0 | 0x00241C | 0x241C

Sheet: CH_3
R112 | 0x700000 |  | <<== Insert channel data at cell A1
R111 | 0x6F0000
R110 | 0x6E0000
R109 | 0x6D0000
R108 | 0x6C0000
R107 | 0x6B0000
R106 | 0x6A0000
R105 | 0x690021
R104 | 0x680000
R103 | 0x670000
R102 | 0x663B00
R101 | 0x650011
R100 | 0x640000
R99 | 0x630000
R98 | 0x621400
R97 | 0x610888
R96 | 0x600000
R95 | 0x5F0000
R94 | 0x5E0000
R93 | 0x5D0000
R92 | 0x5C0000
R91 | 0x5B0000
R90 | 0x5A0000
R89 | 0x590000
R88 | 0x580000
R87 | 0x570000
R86 | 0x560001
R85 | 0x550000
R84 | 0x540001
R83 | 0x53FFFF
R82 | 0x52FFFF
R81 | 0x510000
R80 | 0x500000
R79 | 0x4F0180 | 0x0180,
R78 | 0x4E0003 | 0x0003,
R77 | 0x4D0000 | 0x0000,
R76 | 0x4C000C | 0x000C,
R75 | 0x4B0800 | 0x0800,
R74 | 0x4A0000 | 0x0000,
R73 | 0x49003F | 0x003F,
R72 | 0x480001 | 0x0001,
R71 | 0x470081 | 0x0081,
R70 | 0x46C350 | 0xC350,
R69 | 0x450000 | 0x0000,
R68 | 0x4403E8 | 0x03E8,
R67 | 0x430000 | 0x0000,
R66 | 0x4201F4 | 0x01F4,
R65 | 0x410000 | 0x0000,
R64 | 0x401388 | 0x1388,
R63 | 0x3F0000 | 0x0000,
R62 | 0x3E0322 | 0x0322,
R61 | 0x3D00A8 | 0x00A8,
R60 | 0x3C0000 | 0x0000,
R59 | 0x3B0001 | 0x0001,
R58 | 0x3A9001 | 0x9001,
R57 | 0x390020 | 0x0020,
R56 | 0x380000 | 0x0000,
R55 | 0x370000 | 0x0000,
R54 | 0x360000 | 0x0000,
R53 | 0x350000 | 0x0000,
R52 | 0x340820 | 0x0820,
R51 | 0x330080 | 0x0080,
R50 | 0x320000 | 0x0000,
R49 | 0x314180 | 0x4180,
R48 | 0x300300 | 0x0300,
R47 | 0x2F0300 | 0x0300,
R46 | 0x2E07FC | 0x07FC,
R45 | 0x2DC0DF | 0xC0DF,
R44 | 0x2C1FA3 | 0x1FA3,
R43 | 0x2B0000 | 0x0000,
R42 | 0x2A0000 | 0x0000,
R41 | 0x290000 | 0x0000,
R40 | 0x280000 | 0x0000,
R39 | 0x2703E8 | 0x03E8,
R38 | 0x260000 | 0x0000,
R37 | 0x250404 | 0x0404,
R36 | 0x240240 | 0x0240,
R35 | 0x230004 | 0x0004,
R34 | 0x220000 | 0x0000,
R33 | 0x211E21 | 0x1E21,
R32 | 0x200393 | 0x0393,
R31 | 0x1F43EC | 0x43EC,
R30 | 0x1E318C | 0x318C,
R29 | 0x1D318C | 0x318C,
R28 | 0x1C0488 | 0x0488,
R27 | 0x1B0002 | 0x0002,
R26 | 0x1A0DB0 | 0x0DB0,
R25 | 0x190C2B | 0x0C2B,
R24 | 0x18071A | 0x071A,
R23 | 0x17007C | 0x007C,
R22 | 0x160001 | 0x0001,
R21 | 0x150401 | 0x0401,
R20 | 0x14E048 | 0xE048,
R19 | 0x1327B7 | 0x27B7,
R18 | 0x120064 | 0x0064,
R17 | 0x11012C | 0x012C,
R16 | 0x100080 | 0x0080,
R15 | 0x0F064F | 0x064F,
R14 | 0x0E1E70 | 0x1E70,
R13 | 0x0D4000 | 0x4000,
R12 | 0x0C5001 | 0x5001,
R11 | 0x0B0018 | 0x0018,
R10 | 0x0A10D8 | 0x10D8,
R9 | 0x091604 | 0x1604,
R8 | 0x082000 | 0x2000,
R7 | 0x0740B2 | 0x40B2,
R6 | 0x06C802 | 0xC802,
R5 | 0x0500C8 | 0x00C8,
R4 | 0x040A43 | 0x0A43,
R3 | 0x030642 | 0x0642,
R2 | 0x020500 | 0x0500,
R1 | 0x010808 | 0x0808,
R0 | 0x00241C | 0x241C

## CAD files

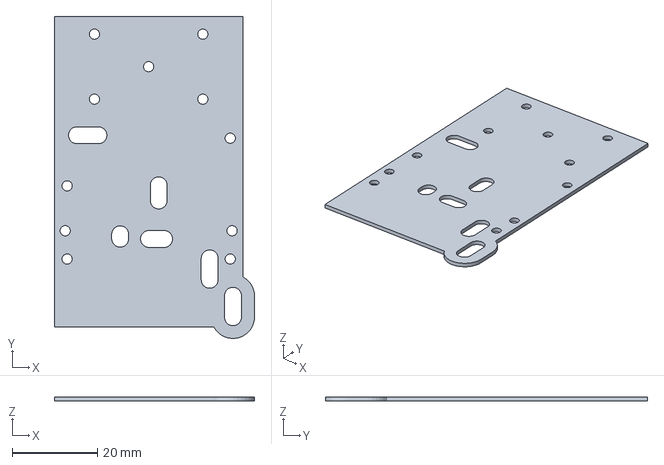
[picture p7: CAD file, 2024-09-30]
Artemis3D/artemis_template.3mf
46.9 x 75.5 x 1.00 mm

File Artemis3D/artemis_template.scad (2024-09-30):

// OpenSCAD 2019.05
// Artemis PCB/heatsink machining template, REV-002
// Joe Haas, KE0FF, 10/28/2023
//
// Rev-002, 09/29/2024
//	Added artefacts for external 5V regulator
//	Adde SMA centerline markers
//
// Rev-001, 10/28/2023
//	initial code

//----------------------------------------------------------------------------------------------------------------------
// User defined parameters.  Modify these to suit a particular application
// NOTE: All data in this file is in mm
//----------------------------------------------------------------------------------------------------------------------
// parametric variables:

thick = 1;
m2m = 25.4/1000; // mils to mm

x0 = 992;
y0 = 700;
hdia = 2.4; //.07*25.4;

width = ((2563-y0)*m2m) + (1000*m2m);
length = (2732-x0)*m2m;

m1x = (1110-x0)*m2m;
m1y = (2000-y0)*m2m;
m2x = m1x;
m2y = (1325-y0)*m2m;
m3x = (2615-x0)*m2m;
m3y = (1325-y0)*m2m;
m4x = m3x;
m4y = (2440-y0)*m2m;
d1x = (1299.5-x0)*m2m;
d1y = (2467-y0)*m2m;
d3x = (2640-x0)*m2m;
d3y = (887-y0)*m2m;
d4x = (2425-x0)*m2m;
d4y = (1232.5-y0)*m2m;
l2x = (1599-x0)*m2m;
l2y = (1533-y0)*m2m;
c60x = (1955-x0)*m2m;
c60y = (1935-y0)*m2m;
c57x = (1935-x0)*m2m;
c57y = (1510-y0)*m2m;
smay = 886*m2m;

genx = 500*m2m;
geny = 300*m2m;

////////////////////////////////////////////////////////////////////////////////

template();
//elipse();

////////////////////////////////////////////////////////////////////////////////


//
//
//**************************************************
				//****************\\
				//    modules     \\
				//    follow      \\
				//****************\\
//**************************************************
//
//
///////////////
// template

module template(){
	difference(){
		// main shape
		union(){
			cube([length,width,thick]);
			// d3 overhang
			translate([d3x,d3y,0]) rotate([0,0,90]) elipse(ww=400*m2m, ll=15, tt=1);
			// d1 overhang
			translate([d1x,d1y,0]) rotate([0,0,0]) elipse(ww=400*m2m, ll=15, tt=1);
		}
		// mtg holes
		translate([m1x,m1y,-1]) cylinder(r=hdia/2, h=3*thick, $fn=32);
		translate([m2x,m2y,-1]) cylinder(r=hdia/2, h=3*thick, $fn=32);
		translate([m3x,m3y,-1]) cylinder(r=hdia/2, h=3*thick, $fn=32);
		translate([m4x,m4y,-1]) cylinder(r=hdia/2, h=3*thick, $fn=32);
		// VREG mtg
		translate([length/2,2400*m2m,-1]) cylinder(r=hdia/2, h=3*thick, $fn=32);
		// reg-module generic mtg
		translate([(length/2)-genx,(2400*m2m)-geny,-1]) cylinder(r=hdia/2, h=3*thick, $fn=32);
		translate([(length/2)-genx,(2400*m2m)+geny,-1]) cylinder(r=hdia/2, h=3*thick, $fn=32);
		translate([(length/2)+genx,(2400*m2m)-geny,-1]) cylinder(r=hdia/2, h=3*thick, $fn=32);
		translate([(length/2)+genx,(2400*m2m)+geny,-1]) cylinder(r=hdia/2, h=3*thick, $fn=32);
		// sma centerline
		translate([100*m2m,smay,-1]) cylinder(r=hdia/2, h=3*thick, $fn=32);
		translate([length-(100*m2m),smay,-1]) cylinder(r=hdia/2, h=3*thick, $fn=32);
		// d1
		translate([d1x,d1y,-1]) elipse(ww=156*m2m, ll=9);
		// d3
		translate([d3x,d3y,-1]) rotate([0,0,90]) elipse(ww=156*m2m, ll=9);
		// d4
		translate([d4x,d4y,-1]) rotate([0,0,90]) elipse(ww=156*m2m, ll=9);
		// l2
		translate([l2x,l2y,-1]) rotate([0,0,90]) elipse(ww=156*m2m, ll=5);
		// c60
		translate([c60x,c60y,-1]) rotate([0,0,90]) elipse(ww=156*m2m, ll=7.5);
		// c57
		translate([c57x,c57y,-1]) rotate([0,0,0]) elipse(ww=156*m2m, ll=7.5);
	}
}

module elipse(ww=10, ll=20, tt=3*thick){
	translate([(ll-ww)/2,0,0]) cylinder(r=ww/2, h=tt, $fn=32);
	translate([-(ll-ww)/2,0,0]) cylinder(r=ww/2, h=tt, $fn=32);
	translate([-(ll-ww)/2,-ww/2,0]) cube([(ll-ww), ww, tt]);
}

/////////////////////////////////////
// generic countersink

module cs(screw=4){
	if(screw == 2){
		translate([0,0,.6]) cylinder(r1=4.57/2, r2=2.18/2, h=1.5, $fn=32, center = true);	// #2 countersinks
	}else{
		translate([0,0,.78]) cylinder(r1=6.02/2, r2=2.84/2, h=2, $fn=32, center = true);	// #4 countersinks
	}
}
/////////////////////////////////////
// SMA connector (fit check artifact)
module sma(){
  union(){
	translate([-4.75,0,-4.6]) cube([9.5,6.7,7.9]);
	translate([0,0,-.75]) rotate([90,0,0]) cylinder(r=3.1, h=7.5, $fn=32);
  }
}

/////////////////////////////////////////////////////
// SMA pilot holes and clearences (part of 3D render)

module sma_pilot(){
	translate([-30.05,-37.7,-6.4]) union(){
		translate([7.75-1.45,-1,-4.1]) cube([12.5,5,7.9]);											// panel face clearance, RF4
		translate([13.3,-.9,-.75]) rotate([90,0,0]) cylinder(r=3.5, h=4.3, $fn=32, center=false);	// barrel pilot, RF4
//		translate([13.3,.1,-.75]) rotate([90,0,0]) cylinder(r=1.5, h=2.5, $fn=32);
		translate([7.75+(47-13.45),-1,-4.1]) cube([12.5,5,7.9]);									// panel face clearance, RF3
		translate([47.5,-.9,-.75]) rotate([90,0,0]) cylinder(r=3.5, h=4.3, $fn=32, center=false);	// barrel pilot, RF3
//		translate([47,.1,-.75]) rotate([90,0,0]) cylinder(r=1.5, h=2.5, $fn=32);
	}
}

/////////////////////////////////////////////////
// Side-mount SMA pilot holes (part of 3D render)

module sma2_pilot(){
  translate([-32,-21+38.2,-6.4]) rotate([0,0,270]) union(){
	translate([7.50,0,-4.1]) cube([12,5,7.9]);
	difference(){	// slope roof
		translate([8.25+5.25,width+.035,-4.1]) rotate([0,90,0]) cylinder(h=12, r=width+.4, $fn=256, center=true);
		translate([6.9,-2,-(width*2)-3-4.1]) cube([15,(width*2)+10,(width*2)+10]);
		translate([6.9,3,-4.1]) cube([15,(width*2)+10,(width*2)+10]);		
	}
	translate([13.3,.1,-.75]) rotate([90,0,0]) cylinder(r=.8, h=8, $fn=32);
//	translate([13.3,.1,-.75]) rotate([90,0,0]) cylinder(r=1.5, h=2.5, $fn=32);
  }
}

/////////////////////////
// scant opening for PBSW

module pbsw(hole=0){
  union(){
	if(hole == 0){
		color("darkslategray",1.0) translate([-3.05,-3.05,0]) cube([6.1,6.1,3.4]);
		color("black",1.0) translate([0,0,0]) cylinder(r=1.7, h=5, $fn=32, center=false);
		color("white",.5) translate([0,0,0]) cylinder(r=.5, h=20, $fn=32, center=false);
	}else{
		translate([0,0,-.1]) cylinder(r=4/2, h=10, $fn=32, center=false);
	}
  }
}

/////////////////////////////
// USB connectors (fit check)

module usb(){
  union(){
	color("silver",1.0) translate([-3.75,-1.1,0]) cube([7.5,5.8,2.5]);
  }
}

/////////////////////
// generic pilot hole

module pilot(diameter=2){
  union(){
	rotate([90,0,0]) cylinder(d=diameter, h=10, $fn=32, center=true);
  }
}

/////////////////////////
// DB9 cutout (3D render)

module db9(){
	translate([0,0,2.05]) union(){
		translate([0,0,0]) cube([18.44,10.06,15], center=true);								// DB9 cutout
		translate([0,0,3.0]) cube([32,14,10.1], center=true);								// DB9 CM
		translate([(101.60-76.20)/2,0,0]) cylinder(r=1.6, h=20, $fn=32, center=true);		// db9 mtg holes,	#1
		translate([-(101.60-76.20)/2,0,0]) cylinder(r=1.6, h=20, $fn=32, center=true);		//				    #2
	}
}

/////////////////////////
// lid corner

module corner(height=5){
			translate([0,0,chamfer]) cylinder(r=crad/2, h=height-chamfer, $fn=32, center=false);			// corner
			cylinder(r1=(crad/2)-chamfer, r2=crad/2, h=chamfer, $fn=32, center=false);
}

/////////////////////////
// debug artifacts
//
// X-rulers
//#translate([-.69,0,0]) cube([0.01,30,50]);	// ruler
//#translate([175.41,0,0]) cube([0.01,30,50]);	// inside main void ruler 1
//#translate([1.67,0,0]) cube([0.01,30,50]);	// inside main void ruler 2
//#translate([175.34,0,0]) cube([0.01,30,50]);	// outside shroud ruler 2
// Y-rulers
//#translate([0,23.81,0]) cube([180,0.01,50]);	// ruler
//#translate([0,22.36 ,0]) cube([180,0.01,50]);	// ruler
// Z-rulers
//#translate([0,0,0]) cube([10,40,.01]);	// ruler
//#translate([0,0,2.04]) cube([9,40,.01]);	// ruler

// EOF

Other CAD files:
Artemis3D/artemis_template.stl

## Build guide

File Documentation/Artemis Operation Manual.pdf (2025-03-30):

## Artemis-I Operation Manual (HW revision -, SW V1.0+)

03/30/2025
Joe Haas, KE0FF
The Artemis-I is a PLL synthesizer based on the TI LMX2594 PLL chip. It utilizes a Microchip ATTINY-3217 microcontroller to configure the synthesizer registers via a serial interface. The following lists the major specifications of this synthesizer:

Frequency range: 4000 MHz to 15000 MHz (operation as low as 2250 Mhz with reduced output) Output level: +12 ±2 dBm at 8000 MHz
Typical Phase Noise @ Fc = 4000 MHz: <TBD>
Typical Phase Noise @ Fc = 15000 MHz: <TBD>
Reference: 25.0000 MHz on-board
External reference selected by de-soldering and moving a chip capacitor and may range from 5 MHz to 1400 Mhz, 0.2 to 2 Vpp (-1 dBm to +19 dBm), Zin = 50Ω
Power supply: +5Vdc, 450 mA (heatsink required)
Communications: TTL UART com, 9600 baud, N81
/MUTE input: GND true, 3.3V compatible, on-board pull-up, GND to mute output Frequency select inputs: 5 bit, binary, GND true, 3.3V logic
Primary connection: 16 pin ribbon header. Connector and cable not supplied. Connector P/N: TE/AMP 1658622-3, Ribbon cable, 16 conductor, 0.05” spacing, any vendor, length as needed (less than 12” recommended).
MCU PGM connection: Atmel UPDI programming via 16 pin connector or optional 6-pin programming connector

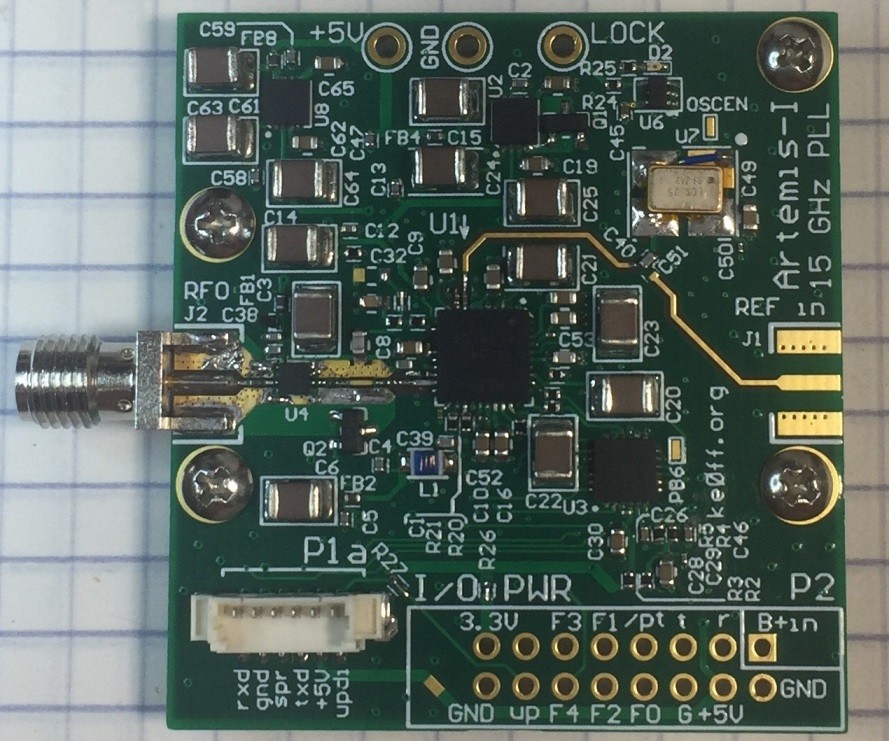
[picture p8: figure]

Figure 1. Artemis-I PLL Synthesizer

© Joseph M. Haas, 03/30/25, all rights reserved | 1 | Artemis-I Operation – Rev-

## Operation

The Artemis operates from a +5Vdc supply. A heat-spreader/heat-sink is required for reliable operation (see Appendix for details). All power and control signals for normal operation are available at the main connector, P2.
P1 Pinout
UPDI | 1 | | Note: See the “SiLabs/Tiva/ATtiny
+5V | 2 | | Programming Guide” (see the bibliography
DBUG_TXD | 3 | | section of this document for a link) for
SPARE | 4 | | more information about this connector.
GND | 5
DBUG_RXD | 6
P2 Pinout
+Vin (n/c) | 1 | 2 | GND
DBUG_RXD (TTL) | 3 | 4 | +5.0V
DBUG-232 TXD (TTL) | 5 | 6 | GND
/MUTE | 7 | 8 | FSEL0 (LSD b0)
(LSD b1) FSEL1 | 9 | 10 FSEL2 (LSD b2)
(LSD b3) FSEL3 11 | 12 FSEL4 (MSD b0)
n/c 13 | 14 UPDI
+3.3V (out) 15 | 16 GND
Note: All logic signals are 3.3V logic and will NOT tolerate higher voltage logic

Note: Optionally, a pre-regulator may be provided to allow a >+10V power source to operate the Artemis. See the appendix for an example.

Frequency Selection (Channels)

The Artemis supports 7 channels (SW V0.3+) providing a user-programmable frequency source. When /MUTE is open (>3.3V), the channel data represented by the binary code presented at the 5 FSEL inputs (only FSEL[2:0] are active at this time) is transferred to the PLL. Each channel consists of 80, 16-bit registers that are transferred to the
LMX2594 when the channel is selected. These registers comprise the entire register set of the LMX2594 and allow for complete control of the PLL functionality. Refer to the LMX2594 datasheet for additional information regarding these registers.

It is recommended that users utilize the TICS Pro evaluation software provided by Texas Instruments when defining a register set for a particular channel definition. From this software, the contents of the can be exported transfer into the Artemis MCU firmware. Programming the channels currently requires reprogramming of the MCU application and covered in a later section of this document.

The 5-bit logic inputs use the pull-up feature of the ATTINY MCU to allow the PLL channel to be selected by applying GND (0V) or open (>+2.5V) levels to the FSEL

© Joseph M. Haas, 03/30/25, all rights reserved | 2 | Artemis-I Operation – Rev-

inputs. To switch channels, simply apply the desired bit pattern (using GND true logic) to the FSEL[4:0] inputs. Note: the MCU will change channels immediately upon detecting a change in the channel setting. Thus, if individual bits are changed over even just a few ms, it may be possible for the Artemis to step through one or more unintended channels as the inputs settle.

“GND-True” means that a grounded bit = logic “1” and an open bit = logic “0”. Thus, channel 3 would be set by leaving FSEL2 open, grounding FSEL1 and FSEL0 (A DIP switch or GND common binary selector switch works well for this purpose), with all other FSEL inputs open or GND .

/MUTE Function

If desired, the /MUTE input can be used to gate the PLL tone. This is useful for keying the output (for a beacon) or to mute the synthesizer for TX/RX transitions. Simply ground the /MUTE input to turn off the PLL, leave the input open to enable the output.

Serial Port

The Artemis MCU features a 3.3V TTL serial connection that can be used to program the MCU channel sets (future) or to provide real-time frequency control of the PLL. An elapsed time indicator and two temperature sensors are periodically reported to allow simple data-logging operations. The serial parameters are 9600 baud, 8 data bits, no parity, one stop bit. At power-on, an initialization banner message is sent by Artemis:

Artemis Help (cmds are case sensitive):
0-7: force-set PLL CH
q: re-sync to FSEL CH
n: tone on
f: tone off
cn: set hex U32 EE cal 'HGFEDCBA' Cn: Read EE cal
on: set hex EE offs 'DCBA'
On: Read U16 EE offs
n = sens#, 1/0
Uu: Set therm unit chr
R: Download data to temp channel reg Rn..n<tab>0xiirrrr
n..n = reg index (dec)
<tab> = ASCII 0x09
0xii = hex qualifier & hex index rrrr = hex reg data
Pc: PGM temp channel to ch# 'c'
t: send download data to PLL
<ENTER>: display ETI(sec)/temp(K) stats T0=regulator, T1=PLL
V: SW Version

a/A: read raw ADC, ch0/1
z: debug sram hex dump
z f: debug FLASH hex dump
© Joseph M. Haas, 03/30/25, all rights reserved | 3 | Artemis-I Operation – Rev-

The reset banner provides the software version and a brief list of version features. Primarily, this message is important for identifying the current software version, and verifying that the UART TX connection to the user terminal is working. Note: The banner message might change with newer software versions.

The serial commands available are as follows:

All commands are 1 or 2 characters plus any required parameters (separated by a single space) and are terminated with <CR> (ASCII 0x0d, <ENTER> or <RETURN> on most keyboards). Note: The ATTINY serial port does not echo characters entered from the host terminal and there is no back-space processing. Commands are case sensitive.

<ESC>: Escape key (ASCII 0x1B), abort entry
Single-key command. Flushes the command buffer and displays “>>Abort<<” message.

?: List Command Help
Displays an abbreviated list of the available commands.

0 – 7: Select Channel
Performs a channel selection just as if the logic inputs were set. The FSEL logic inputs will be superseded until they change state.

q: Re-sync to FSEL Channel
This command can “reset” the Artemis to use the current FSEL setting after manually changing the channel settings with the “0 – 7” or “t” commands.

n: Tone on
Enables the PLL output. Same as opening the /MUTE input. The /MUTE input is superseded until it changes state.

f: Tone off
Disables the PLL output. Same as grounding the /MUTE input. The /MUTE input is superseded until it changes state.

<Enter>: with no or an invalid command, displays the PLL status message
An example message:

T0:323.4 K; T1:321.6 K; ETI: 3

T0 is the regulator temperature, T1 is the PLL temperature, the ETI is the number of seconds since power on. Temperatures are in Kelvins – subtract 273 to get the temperature in C. Note: The sensors are located “near” their respective heat sources, but not extremely close, from a thermal perspective. For example, the PLL sensor reads about 10C lower than the PLL case temperature.

© Joseph M. Haas, 03/30/25, all rights reserved | 4 | Artemis-I Operation – Rev-

a | Read raw A/D value for sensor0
A Read raw A/D value for sensor1

The raw ADC values are used to create the sensor cal settings for the temperature sensors. See below.

Temperature Calibration Support Commands:
c0 hhhhhhhh | Set sensor0 slope calibration
o0 hhhh | Set sensor0 offset calibration
c1 hhhhhhhh | Set sensor1 slope calibration
o1 hhhh | Set sensor1 offset calibration
C0 | Read sensor0 slope calibration
O0 | Read sensor0 offset calibration
C1 | Read sensor1 slope calibration
O1 | Read sensor1 offset calibration
Uu | Set temperature unit character

“h” is a hex digit (0 – 9, A – F, case insensitive).

These values are all stored to the MCU EEPROM and are not erased when the MCU firmware is reprogrammed.

Calculation of the “h..h” parameters requires an accurate temperature measurement device to measure the air temperature in the vicinity of the Artemis unit. The procedure is to start with the Artemis at room temperature (it should rest with no power applied for at least 2 hours). Once the Artemis temperature is stabilized, ground the /MUTE signal, start the terminal emulator with an appropriate serial interface configured and then apply power to the Artemis.

Next, wait 60 seconds and then read the raw ADC values for each sensor (“a” and “A” commands) Also, read the ambient temperature near the Artemis. Record the ADC and temperature values. Use the Windows Calculator in Programmer mode to convert hex values to decimal. After the calculation of the cal value, use the calculator to convert decimal to hex.

The cal value, “Xa” is calculated as follows: Xa = T(K) * 10 * RawADC

Round the result to the nearest integer, convert Xa to hex, and add leading zeros so that it is 8 digits total. Enter this value using the “cn hhhhhhhh” command where “n” is the sensor# and “h..h” is the hex value. A single space (ASCII 0x20) between “n” and the first “h” is required, and spaces between “h” digits are not allowed. Each sensor may have its own value for Xa calculated.

Set the offset values to “0000”. The offset is for advanced calibration schemes or other unit displays and is not required for this procedure. The raw ADC data is buffered and

© Joseph M. Haas, 03/30/25, all rights reserved | 5 | Artemis-I Operation – Rev-

can require several seconds (up to a couple of minutes) for the buffer to fill and provide valid, filtered data. This is true when the Artemis is first powered as well.

For the “Uu” command, “u” is the unit character (“K” is the default”). This may be any printable ASCII character. To produce “C” units, follow the above procedure and then set the offset for each sensor to 0xF556 (-2730) and enter “UC”. Note: The units must match for both sensors.

Rd..d<tab>0xiihhhh Set register “d..d” (decimal) to “hhhh” (hex)

This command accepts a line from the TICSpro export file (unmodified) and stores it into the temporary PLL channel (stored in SRAM). Using a simple ASCII transfer, with 1 ms of line delay, the Artemis can accept the raw output file (via a terminal emulator) to transfer the register contents into temporary memory. Register numbers greater than 79 are ignored. The registers must be processed in decreasing order once “R79” is received. Further, the “d..d” decimal index value must match the “ii” hex index value on the same line or an error results.

To send a file, consult your terminal emulator documentation (TeraTerm instructions are presented below for reference). Currently, only simple ASCII transfers are supported. No handshaking is utilized, but a minimum 1ms delay must be applied by the terminal emulator for each line of ASCII sent. This allows the Artemis time to process the data and be ready for the next register line.

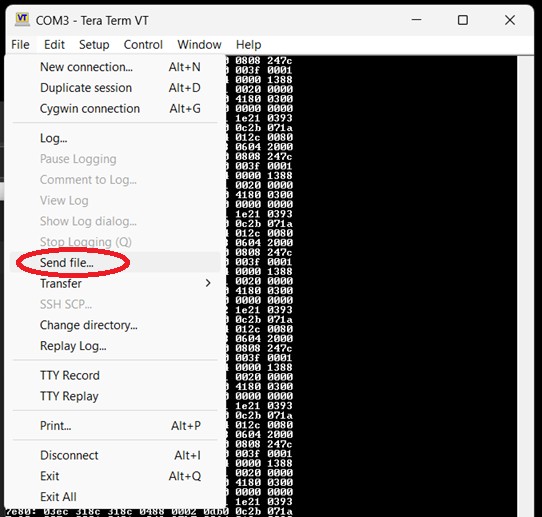
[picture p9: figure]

In TeraTerm, select “File->Send File”:

© Joseph M. Haas, 03/30/25, all rights reserved | 6 | Artemis-I Operation – Rev-

The following dialog box appears:

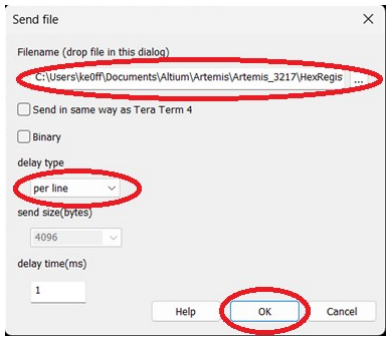
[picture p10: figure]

Select the file, set the delay type, and click “OK”. It takes about 3 seconds for the file to transfer after which an “OK” or “Error” message is displayed. If “OK”, the “t” or “P” commands may be used to test the channel or program it to FLASH.

t | Send temporary channel data to PLL

This command sends the contents of the temporary channel (held in SRAM) to the PLL chip. The PLL will configure just as if the data were programmed in FLASH until a new FSEL setting is presented or a new channel command is entered into the CLI. An “interlock-flag” is used to prevent the “t” command from executing if a valid file transfer has not taken place since power-on.

Pn | Program temporary channel to FLASH CH# “n”

Stores the temporary channel to permanent storage in FLASH. Note: The “P” command automatically erases the previous channel data, so there is no need for an “Erase” command. An “interlock-flag” is used to prevent the “P” command from executing if a valid file transfer has not taken place since power-on.

V: Display software version

z | Hex dump for temporary channel
z f | Hex dump for all FLASH channel

These are debug commands and should not normally be needed.

; | Null command

This allows optional comments to be embedded in channel files to aid with file management. Any text after the “;” up to <EOL> is ignored.

© Joseph M. Haas, 03/30/25, all rights reserved | 7 | Artemis-I Operation – Rev-

BOOTEND Fuse Error

If the MCU is first programmed, or if it was previously operated with a SW version prior to V1.0, the following message will likely appear at power-up:

==========================
>>> BOOTEND FUSE ERROR <<<
==========================

If this happens, follow the instructions for setting the BOOTEND fuse illustrated in the appendix.

TICS Software

The TICS software is the easiest way to define a register set for the LMX2594 and experiment with different LMX2594 register settings. This software can be downloaded at no charge from the TI web site (see the Bibliography/Links section at the end of this document. Note, a log-in account is required, but is free to establish).

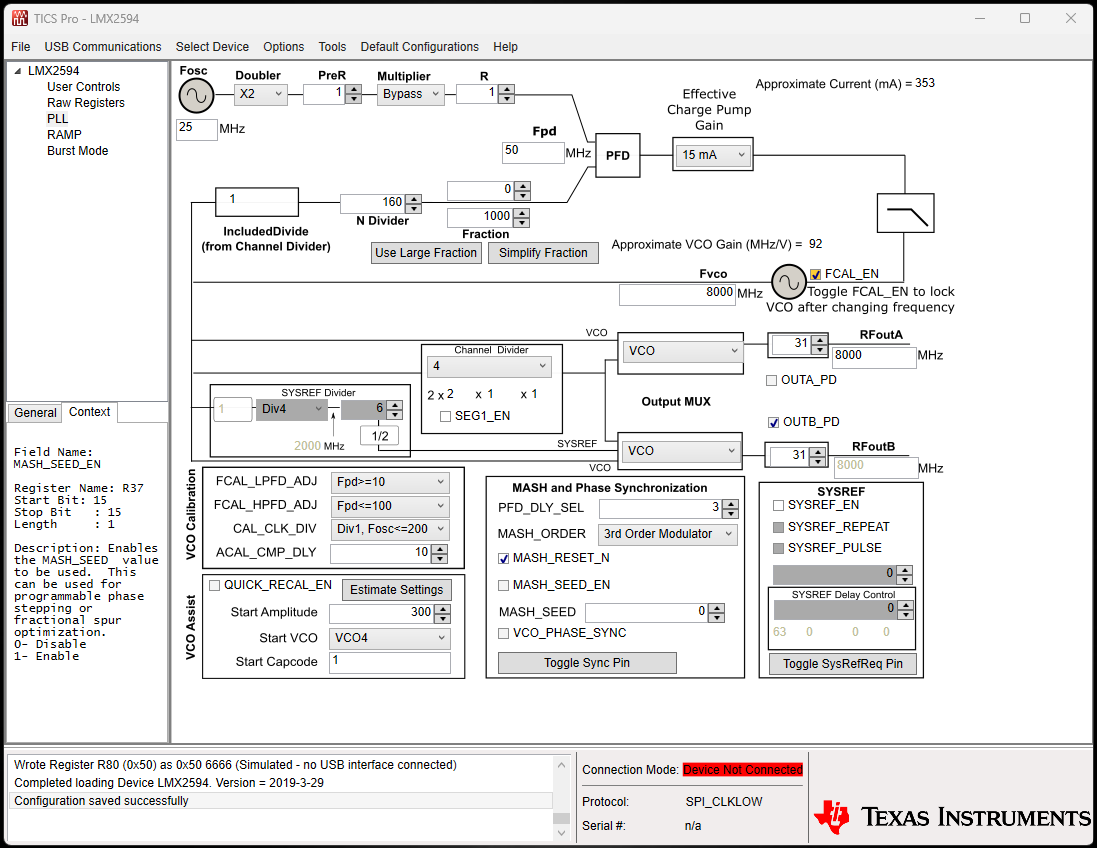
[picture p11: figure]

Figure 2. TICS Main Controls screen (selected by clicking “PLL” in the upper left pane).

© Joseph M. Haas, 03/30/25, all rights reserved | 8 | Artemis-I Operation – Rev-

Figure 2 illustrates the Main Controls screen of the software. Note: this software has the ability to communicate directly with the TI Evaluation board for the LMX2594. However, this functionality is not available with the Artemis board. Once the software is installed, the first step is to select the LMX2594 device as shown in Figure 3.

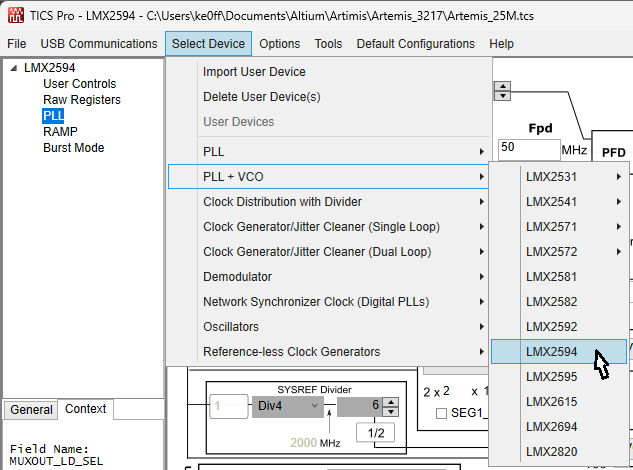
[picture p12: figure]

Figure 3. Device selection in the TICS application

Next, set the reference frequency. It is a good idea to save the configuration to allow later retrieval and to guard against the TICS software closing unexpectedly (it is known to do this on some machines). Under “File” choose “Save” and provide a meaningful filename (include the reference frequency, for example).

Also, be sure to confirm that the lock detect output is configured. This allows the LED to provide lock status:

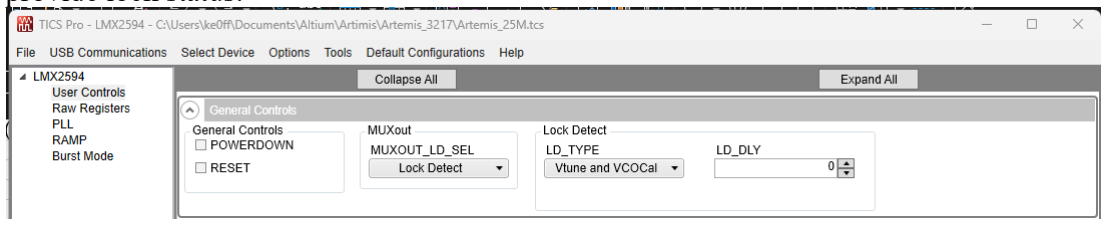
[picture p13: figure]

It is best to start with the default settings to the extent possible. The main items that must be filled in for a given frequency are as follows:

Reference Frequency: 25 MHz for the standard Artemis configuration (if a different reference is used, then that value is entered)
RFoutB: Enter the desired output frequency in MHz
OUTB_PD: Un-checked
RFoutA: do not adjust
OUTA_PD: Checked
RF Output Level: This is the unit-less numeric field next to the “RFoutB” text. 31 is the maximum effective setting. Values from 0 – 31 are considered usable.
© Joseph M. Haas, 03/30/25, all rights reserved | 9 | Artemis-I Operation – Rev-

The reference settings might require additional adjustment to allow fine-resolution frequencies to be selected. Refer to the LMX2594 datasheet and TICS help files for explanations of the other fields on this screen.

The TICS software updates the register settings in real time as the fields are updated. Settings that result in an illegal configuration or other known conflict will be indicated by “shading” of the respective setting field. The user may hover their mouse pointer over the field for a detailed message as to the nature of the problem and what should be done to correct it. The advice offered is generally acceptable.

Once a configuration is complete and there are no warnings displayed (the “FCAL_EN” check-box warning is for the TI Evaluation board connection and can be ignored), the register settings can be exported to allow them to be copied into the ATTINY source code. Under “File”, select “Export hex register values”:

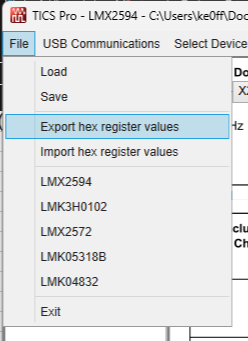
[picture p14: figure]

And provide a meaningful filename. This file is a plain-text file (so use a “.txt” extension) that has a list of the register addresses and values. Note that this list is not immediately usable by the ATTINY compiler but may be downloaded as-is to the Artemis CLI serial port using suitable terminal emulator software.

If the data is to be placed in the “channels.c” source file, the desired data must be extracted first which is most easily accomplished by using Excel (2013 or later) or LibreOffice Calc (version 7.6 or later). An example file is included in the github repo, titled “register_extract.xlsx”. Follow the instructions in the spreadsheet for producing the output needed for the ATTINY compiler. The resulting data is copied and pasted into the “channels.c” source file, found in the ATTINY project “src” folder. Once all of the channels are copied into the source folder, the code may be compiled (F7) and loaded into the Artemis controller (green right-arrow).

© Joseph M. Haas, 03/30/25, all rights reserved | 10 | Artemis-I Operation – Rev-

Artemis Frequency Response

The LMX2594 can produce frequencies from 10 MHz to 15 GHz. That is over 3 decades of frequency range. However, the frequency response of the device varies over that range. In addition, the choice of buffer amplifier introduces its own influence on the frequency response of the Artemis output. In addition, cables and connectors introduce frequency dependent losses. The PMA2-183LN+ amplifier is specified to operate in the 4 to 15 GHz range, which covers the target range desired for the Artemis project (other synthesizers are available for the <4GHz range). However, the PMA2-183LN+ has some usable gain below 4 GHz, so it might be possible to use to as low as 2.25 GHz (no guarantees, however).

Figure 4 illustrates the Artemis response with the PMA2-183LN+. This plot represents a single sample, so it is for reference only. Performance at any given frequency must be verified by the user.

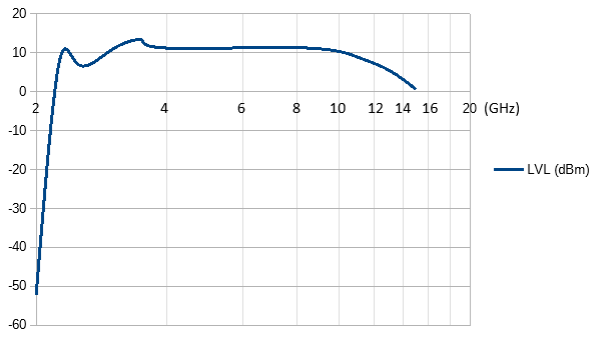
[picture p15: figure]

Figure 4. Representative frequency response of the Artemis synthesizer

© Joseph M. Haas, 03/30/25, all rights reserved | 11 | Artemis-I Operation – Rev-

MCU Programming Cable Connections

In order to program the MCU software or channel data using the MCU programming tools, the Microchip IDE compiler/debugger must be used with a suitable programming adapter. The programming adapter can be constructed with components available from DigiKey or Mouser. Instructions are found in the “SiLabs/Tiva/ATtiny Programming Guide” (see the Bibliography for a web link).

The debug adapter connects to P1 (see Figure 5). Follow the programmer instructions to compile and upload a new FLASH program to the MCU. Note: The 1-wire UPDI programming signal is also exposed on P2-14 making it possible to route the programming signal outside the PLL enclosure for ease of access. UPDI and GND are the only signals needed to connect to an external programming interface.

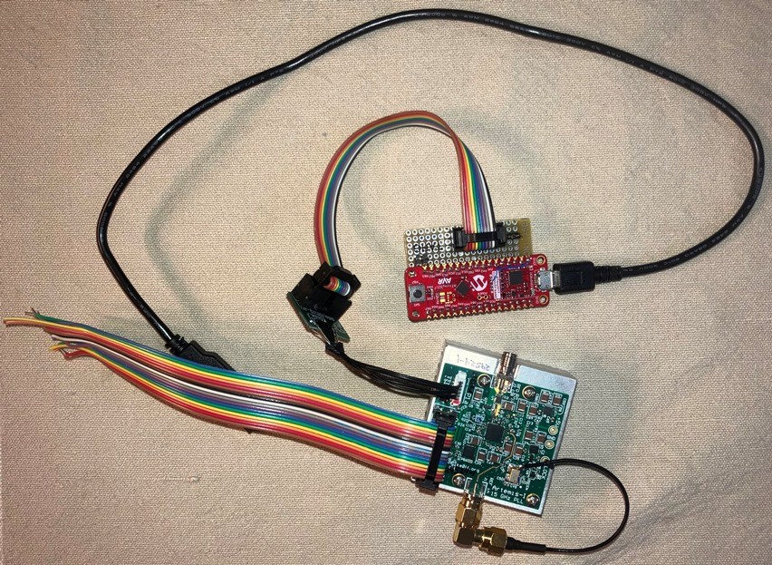
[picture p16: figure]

Figure 5. ATTINY programmer connection to the Artemis board

UART Connections

The Debug RXD and TXD connections (3.3V TTL) are available at P2-3 and P2-5, respectively. To exercise this option, a 3.3V TTL USB com port adapter must be used (Available on Amazon.com: DTech USB to TTL Serial 3.3V Adapter Cable TX RX Signal 4 Pin 0.1 inch Pitch Female Socket PL2303 Prolific Chip Windows 10 8 7 XP Vista (6ft, Black) : Electronics (https://www.amazon.com/Serial-Adapter-Signal-Prolific-Windows/dp/B07R8BQYW1) or other models that provide a UART COM port with 3.3V CMOS (sometimes referred as TTL) logic interface).

Alternatively, the ATTINY CuriosityNano Programmer, described in the “SiLabs/Tiva/ATtiny Programming Guide” (see the Bibliography for a link) can be used as a USB COM port for the Artemis board.

© Joseph M. Haas, 03/30/25, all rights reserved | 12 | Artemis-I Operation – Rev-

Bibliography/References

- TICS Software: https://dr-download.ti.com/secure/software-development/support-software/MD-xsZ2KP7U5k/1.7.7.5/TICSPro_1.7.7.5_23-Jul-2024.exe (https://dr-download.ti.com/secure/software-development/support-software/MD-xsZ2KP7U5k/1.7.7.5/TICSPro_1.7.7.5_23-Jul-2024.exe)
- LMX2594 datasheet: https://www.ti.com/product/LMX2594?keyMatch=LMX2594&tisearch=universal_search&usecase=GPN-ALT (https://www.ti.com/product/LMX2594?keyMatch=LMX2594&tisearch=universal_search&usecase=GPN-ALT)
- Artemis github repo: https://github.com/ke0ff/artemis_pll
- Mini Circuits product page for the PMA2-183LN+: https://www.minicircuits.com/WebStore/dashboard.html?model=PMA2-183LN%2B (https://www.minicircuits.com/WebStore/dashboard.html?model=PMA2-183LN%2B)
- SiLabs/Tiva/ATtiny Programming Guide: https://ke0ff.github.io/Orion/silabspgm.pdf
- Channel formatting spreadsheet: https://github.com/ke0ff/artemis_pll/blob/main/register_extract.xlsx
© Joseph M. Haas, 03/30/25, all rights reserved | 13 | Artemis-I Operation – Rev-

Appendix A
Installation and Application Notes

The Artemis mounting holes are sized for 2-56 screws (0.11” diameter clearance hole). Figure 6 illustrates the outline drawing of the Artemis including mounting hole locations. 8 screws and 4 standoffs are included with the Artemis kit. Replacement screws and standoffs may be obtained from McMaster-Carr (www.mcmaster.com) or other hardware supplier:

Screws, 2-56 x 0.250” (McMaster PN: 91772A077), QTY 4
Spacer, #2 x 0.0625” (McMaster PN: 92510A378), QTY 4

A heatsink is required for proper operation of the Artemis board. Figure 7 illustrates the drill/mill template for the mating surface of the heatsink (the source and P/N are in the BOM, shown later in this document). This template is available as a 3D printable model on the Artemis github.com repo. There are provisions to accommodate an external 5V regulator on the heatsink (user provided). A good, ultra-low-noise design is recommended.

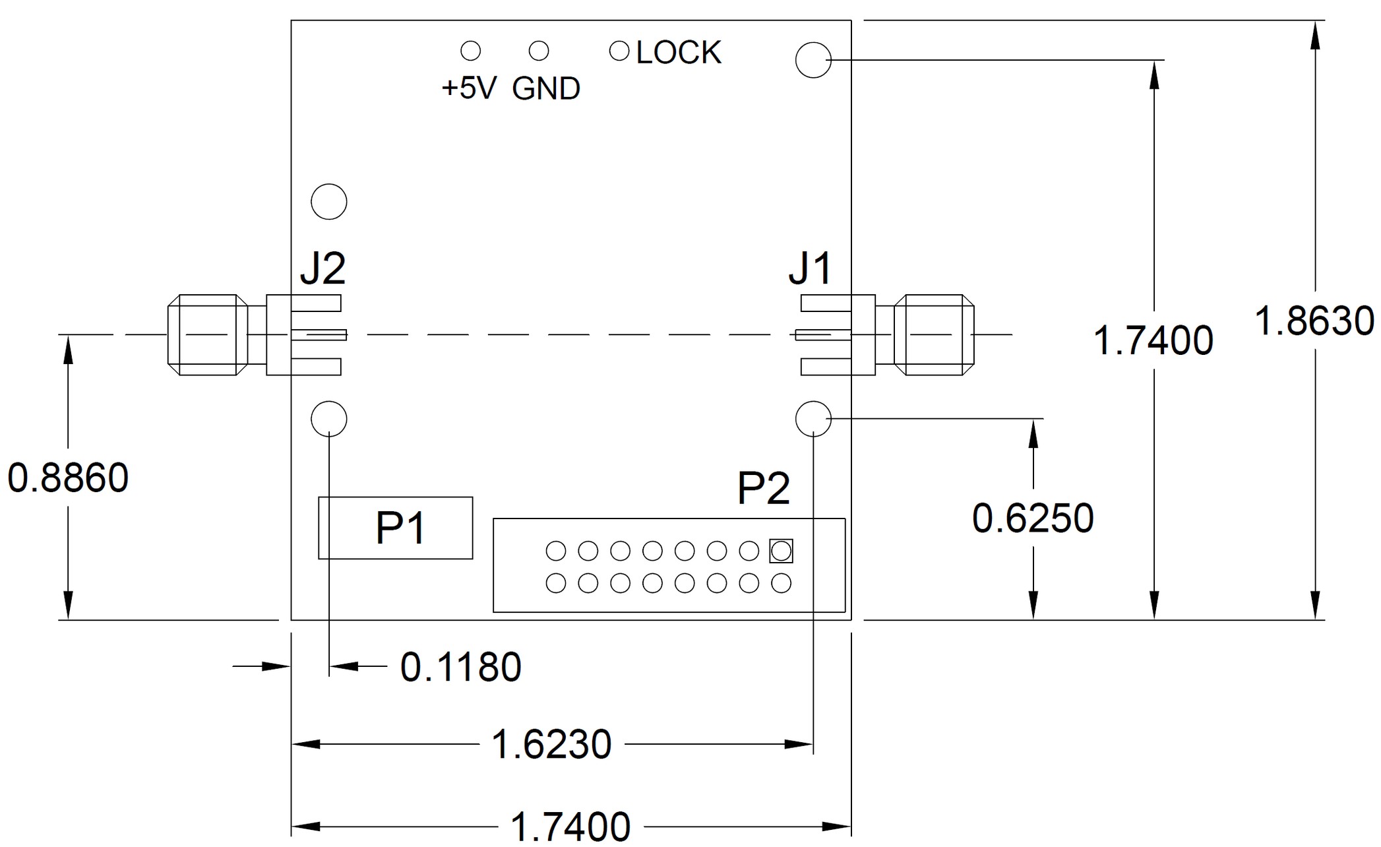
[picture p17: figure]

Figure 6. Artemis mechanical dimensions

© Joseph M. Haas, 03/30/25, all rights reserved | 14 | Artemis-I Operation – Rev-

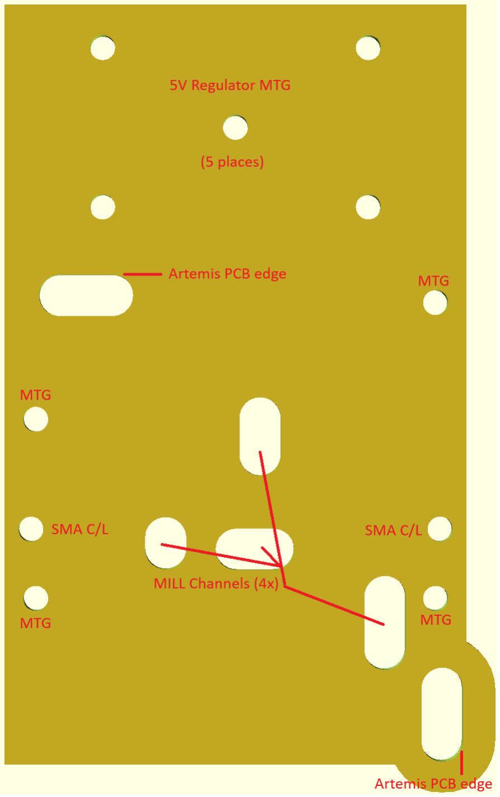
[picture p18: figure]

Figure 7. Artemis Heat-sink drill/mill template (dims in mils) MTG holes are 2-56 drill and tap, 300 deep (8 places) Center 5V regulator hole is 4-40 drill and tap, 300 deep Mill channel (ϕ187.5) depths: (A) 95, (B) 102 (C) 60
SMA C/L troughs milled with ϕ500 end mil, offset 105 from top
© Joseph M. Haas, 03/30/25, all rights reserved | 15 | Artemis-I Operation – Rev-

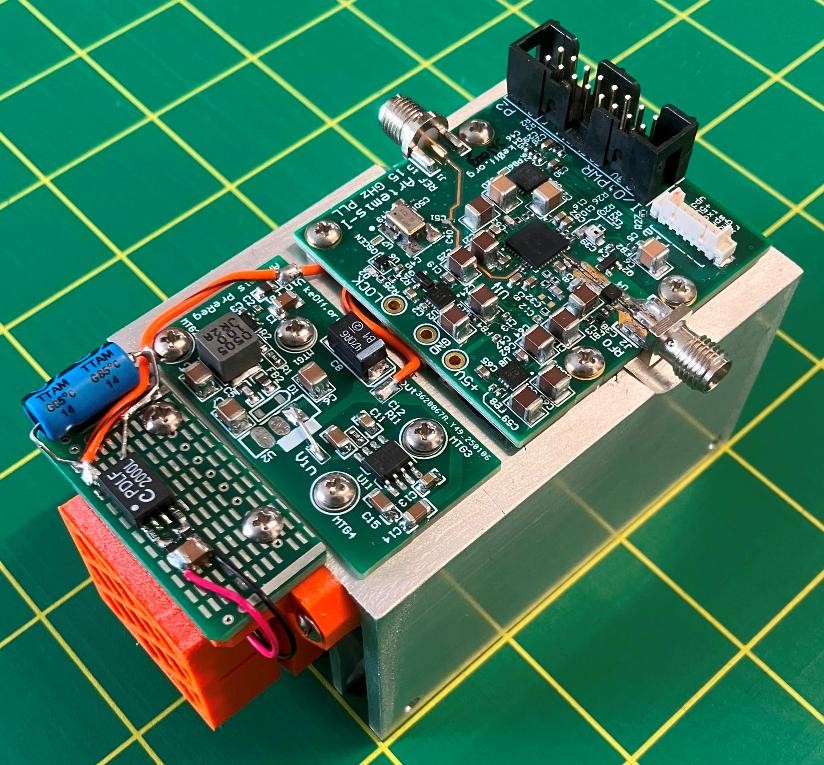
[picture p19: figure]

Photo 1. Artemis with Heatsink, optional low-noise switching pre-regulator, and optional fan.

© Joseph M. Haas, 03/30/25, all rights reserved | 16 | Artemis-I Operation – Rev-

RF Filtering

The Artemis PLL is an excellent signal source with a very wide tuning range. The Artemis is suitable for a transverter or transceiver LO source, or a lab instrumentation source. It is also a popular debug tool for field testing receivers when roving.

For all of its flexibility, there is one thing that must be considered when using the Artemis: filtering is required to reduce the harmonic output of the PLL. For some output settings, the harmonic output can be as high as -16 dBc or more. For instrumentation applications, this may not be a serious issue. However, for communications transceiver applications, these spurs must be reduced to preserve signal purity and system performance. Generally, a suitable low-pass filter will have an Fc somewhat above the desired output frequency (to reduce pass-band attenuation) and a stop band that extends to at least 5Fc. At least 30 dB at 2Fc and 35 dB of stop-band attenuation at or above 3Fc is a good general purpose target for most applications. This will generally provide -45 dBc or better harmonic perfomance.

Small SMA filters, such as available from MiniCircuits, are easy to implement, and are not terribly costly – they simply attach to the Artemis output via an appropriate adapter. For LO and other mixer applications, reflectionless filters are recommended as these present a consistent input/output impedance even in the stop-band. However, these can be more difficult to find and implement, so they are not often an easy option. A buffer with high-isolation can be used after the filter if it is a good match to 50 ohms in the stop-band. This may also require an attenuator if the buffer produces too much signal for the mixer. The attenuator should follow the buffer if possible and should offer a good output match across the entire bandwidth of the mixer.

Filtering for wide bandwidth applications (about an octave of bandwidth or greater) is difficult to manage. This is because the output frequency varies over the harmonic range of the lowest desired output. This means that a filter that is good for the lower frequencies will attenuate the higher frequencies and a filter optimized for the higher frequency will not provide sufficient attenuation to the 2

nd harmonic. In these cases, either a switched filter arrangement or a tunable filter, such as a YIG Tuned Filter (YTF), must be used. Both options represent a complicated compromise that will require considerable care and effort to produce.

Fortunately, most wide-band applications are geared towards instrumentation where other instruments that are part of the measurement suite might be expected to provide some semblance of filtering or other immunity to harmonics emitted by the Artemis reference source.

© Joseph M. Haas, 03/30/25, all rights reserved | 17 | Artemis-I Operation – Rev-

MCU Fuse Programming (New MCU or upgrade from versions prior to 1.0)

Artemis V1.0 requires that the MCU fuses be updated for any version deployed prior to V1.0. To accomplish this, use the Atmel Studio 7 application. !! This step only needs to be performed once !!

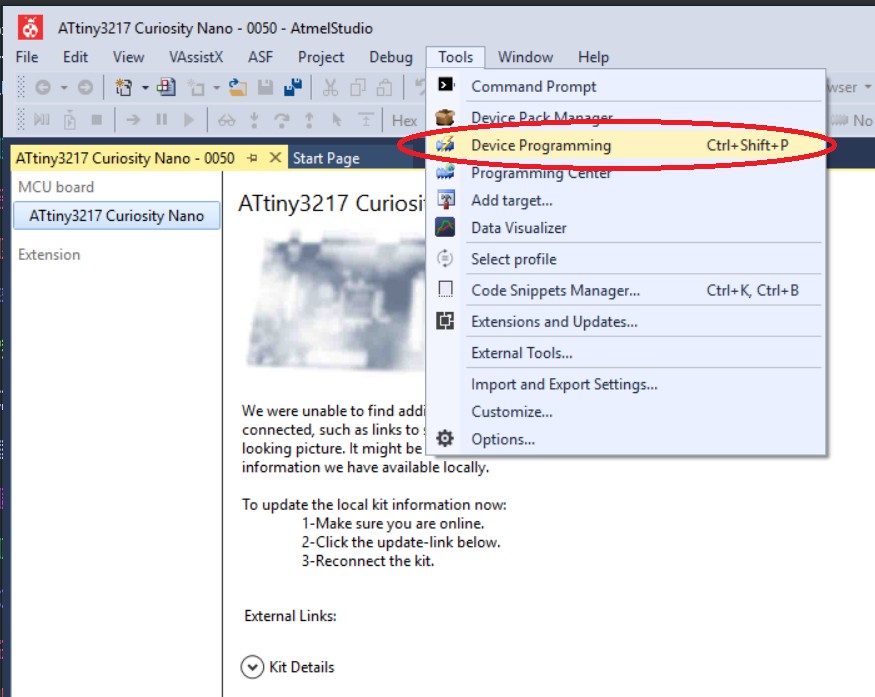
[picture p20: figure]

Connect the programming adapter between the
PC and the Artemis and apply power. Start the
Atmel Studio 7 application and then use the
following steps to connect to the target via the programming adapter:

Select “Tools→Device Programming”

Select “Apply”:

Click “Fuses” (1) and scroll (2) to the bottom of the field-window.

(3) Enter 0x76 into the BOOTEND field. !! DO NOT ADJUST ANY OTHER FIELD !!

Last, (4) click “Program” and verify that the programming operation completes without error.

Click close (5).

The Artemis should now be able to program the FLASH channels.

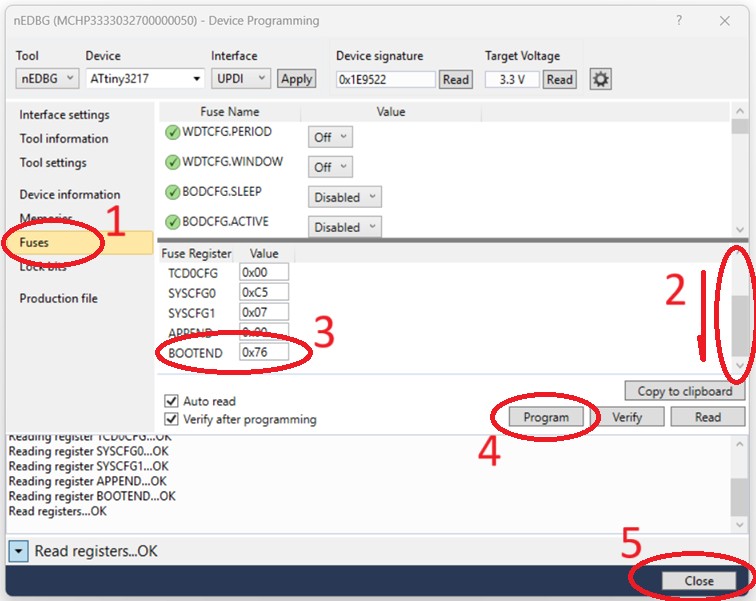
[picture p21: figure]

© Joseph M. Haas, 03/30/25, all rights reserved | 18 | Artemis-I Operation – Rev-

Appendix B
Schematic and BOM

Bill Of Materials

Qty Designator | Description | MFR | MPN
4 | C1, C29, C31, C50 | CAP, MLCC, X5R, 0201, 25V, 10%, 0.1uF | Taiyo Yuden | GMK063BJ104KP-F
10 C2, C4, C5, C12, C13, C47,
| C48, C56, C58, C59 | CAP, MLCC, C0G, 0402, 100V, 10%, 1000pF | Kemet | C0402C102J1GEC7411
3 | C26, C45, C46 | CAP, MLCC, X5R, 0402, 25V, 10%, 0.1uF | Murata | GRM155R71H104KE14D
2 | C27, C65 | CAP, MLCC, X7R, 0603, 50V, 10%, 1uF | Taiyo Yuden | UMK107AB7105MA-T
15 C3, C6, C14, C15, C20,
| C21, C22, C23, C24, C25, C57, C60, C61, C63, C64 | CAP, MLCC, X7R, 1210, 50V, 10%, 10uF | Kemet | C1210C106K5RACTU
1 | C33 | CAP, MLCC, C0G, 0603, 100V, 10%, 1800pF | Murata | GRM1885C2A182JA01D
1 | C34 | CAP, MLCC, C0G, 0603, 50V, 10%, 0.068uF | TDK | VJ0603Y683KXACW1BC
1 | C35 | CAP, MLCC, C0G, 0603, 50V, 10%, 390pF | TDK | C1608C0G2A391K080AA
1 | C36 | CAP, MLCC, C0G, 0402, 50V, 5%, 1000pF | Murata | GRM1555C1H102FA01D
1 | C37 | CAP, MLCC, C0G, 0402, 50V, 5%, 100pF | Murata | GRM1555C1H101JA01J
1 | C38 | CAP, TANT, SMD, 0402, 0.33uF, 20V | ROHM Semi | TCTU1D334M8R
3 | C39, C44, C51 | CAP, MLCC, C0G, 0402, 16V, 10%, 10000pF | Murata | GRM1555CYA103GE01D
3 | C41, C42, C43 | CAP, MLCC, C0G, 0201, 16V, 10%, 0.1uF | Passives Plus | 0201BB104KW160
2 | C52, C53 | CAP, MLCC, C0G, 0201, 100V, 10%, 1000pF | Murata | GRM0335C1H102GE01D
2 | C54, C55 | CAP, MLCC, C0G, 0201, 16V, 10%, 10000pF | Taiyo Yuden | MSASU063SB5103KFNA01
13 C7, C8, C9, C10, C11, C16,
| C17, C18, C19, C28, C30,
| C49, C62 | CAP, MLCC, X7R, 0603, 50V, 10%, 1uF | Taiyo Yuden | MSASU168AB7105KTNA01
2 | D1, D4 | DIO, 50V, SHTKY, SMA | MCC | SS2150-LTP
1 | D2 | LED, 0402, GRN | Kingbright | APG1005CGC-T
1 | D3 | DIO, TVS, 15V, 500W | MCC | SMAJ16A-TP
8 | FB1, FB2, FB3, FB4, FB5,
| FB6, FB7, FB8 | Bead, Ferrite, SMD, 80 ohm | Laird | MI0402K121R-10
2 | J1, J2 | CONN, SMA, EDGE | TE Connectivity | CONSMA003.062
2 | L1, L2 | IND, CHP, WW, 2.7nH, 0805 | Murata | LQW2BAS2N7J00L
0 | P1 or P1a | CON, PICBLD, 1.25MM, 6POS (optional) | Molex | 53398-0671
1 | P2 | CON, DIP, 16 POS | 3M | D2516-6002-AR
1 | P2-mate | CON, IDC, 16 POS | 3M | D89116-0031HK
6 | P2-cable (per inch) | CBL, RBN, 16 POS | 3M | 3801/16
2 | Q1, Q2 | TRAN, PNP, 40V, 100mA, 4.7K bias | OnSemi | MMUN2132LT1G
1 | R1 | RES, CHP, 0402, 1%, 100ppm/C, 1 | Vishay/Dale | RCC04021R00FKED
9 | R10, R11, R12, R13, R14,
| R16, R18, R19, R24 | RES, CHP, 0402, 1%, 33 | Yageo | RC0402FR-0733RL
2 | R15, R17 | RES, CHP, RF, 0402, 0.1%, 50 | Vishay/Dale | FC0402E50R0BST1
1 | R2 | RES, CHP, 0402, 1%, 470 | Yageo | RC0402FR-07470RL
4 | R20, R21, R22, R23 | RES, CHP, 0201, 1%, 49.9 | Yageo | RC0201FR-0749R9L
1 | R25 | RES, CHP, 0402, 1%, 402 | Yageo | RC0402FR-07402RL
1 | R2a | RES, CHP, 0402, 1%, 49.9 | Yageo | RC0402FR-0749R9L
1 | R3 | RES, CHP, 0402, 1%, 4.99 | Yageo | RC0402FR-074R99L
2 | R4, R5 | RES, CHP, 0402, 1%, 3.60K | Yageo | RC0402FR-073K6L
4 | R6, R9, R26, R27 | RES, CHP, 0402, 1%, 0 | Yageo | RC0402FR-070RL
1 | R7 | RES, CHP, 0402, 1%, 18 | Yageo | RC0402FR-0718RL
1 | R8 | RES, CHP, 0402, 1%, 68 | Yageo | RC0402FR-0768RL
1 | U1 | IC, PLL, w/VCO, 7.3-15000 MHz, 300MHz REF | TI | LMX2594RHAT
2 | U2, U8 | IC, VREG, ULN, 3.3V | Analog Devices | ADM7154ACPZ-3.3-R7
1 | U3 | IC, MCU, SFF, 8b, 32Kb, 20MHz | MicroChip | ATTINY3217-MNR
1 | U4 | MMIC, AMP, E-PHEMT | Mini Circuits | PMA2-183LN+
1 | U6 | IC,GATE,2IN,AND,SNGL, | TI | SN74AHC1G08DCKR
1 | U7 | IC, OSC, SMD, W_EN | ECS | ECS-TXO53-S3-33-250-BN-TR
ALT U7 | IC, OSC, SMD, W_EN | Abracon | ASEMB-25.000MHZ-LC-T
1 | PCB | PCB, Artemis-I, Rev - | ANY | Artemis-I
1 | THP1 | Pad, Thermal, 1”x1” | Laird | A15959-07
1 | HS1 | Heat Sink, 2”x3”, 5W – heatsinkonline.com | heatsinkonline.com | 253AS
© Joseph M. Haas, 03/30/25, all rights reserved | 19 | Artemis-I Operation – Rev-

5V Pre-Regulator CCA Bill Of Materials

QTY Designator | Description | MFR | MPN
1 | C1 | CAP, MLCC, X7R, 1210, 100V, 10%, 2.2uF | AVX | 12061C225K4T2A
2 | C2, C3 | CAP, MLCC, X5R, 0402, 50V, 10%, 0.1uF | Murata | GRT155R71H104KE01D
3 | C4, C6, C7 | CAP, MLCC, X7R, 1210, 25V, 10%, 22uF | Samsung | CL32B226KAJNNNE
1 | C5 | CAP, MLCC, C0G, 0805, 100V, 10%, 1000pF | Walsin | 0603N102G101CT
1 | C8 | CAP, TANT, 2917, 6.3V, 10%, 470uF | Vishay | TR3E477K6R3C0050
3 | C11, C14, C15 | CAP, MLCC, X7R, 1206, 50V, 10uF | Samsung EM | CL31B106KBHNNNE
2 | C12, C13 | CAP, MLCC, X7R, 0805, 50V, 1uF | Samsung EM | CL21B105KBFNNNE
1 | FB1 | FB, 0805, 600 ohm, 2A | Fair-Rite | 2508056017Y2
1 | FB2 | FB, 0805, 600 ohm, 2.3A | Murata | BLM21SP601SN1D
1 | L1 | IND, 1819, 10uH, 5.4A | Coiltronics | EXL1V0505-100-R
1 | R1 | RES, CHP, 0603, 1%, 100ppm/C, 9.31K | Yageo | RC0603FR-079K31L
2 | R2, R11 | RES, CHP, 0603, 1%, 100ppm/C, 1.0K | Yageo | RC0603FR-071KL
1 | U1 | IC, REG, SW, BUCK, SOT-23-6 | TI | LMR51420XDDCR
1 | U11 | IC, REG, ULN, 5.0V, SO8-EP | Analog Devices | ADM7150ARDZ-5.0
1 | N/A | PCB, Artemis_PreReg | Any | Artemis-PreReg
© Joseph M. Haas, 03/30/25, all rights reserved | 20 | Artemis-I Operation – Rev-

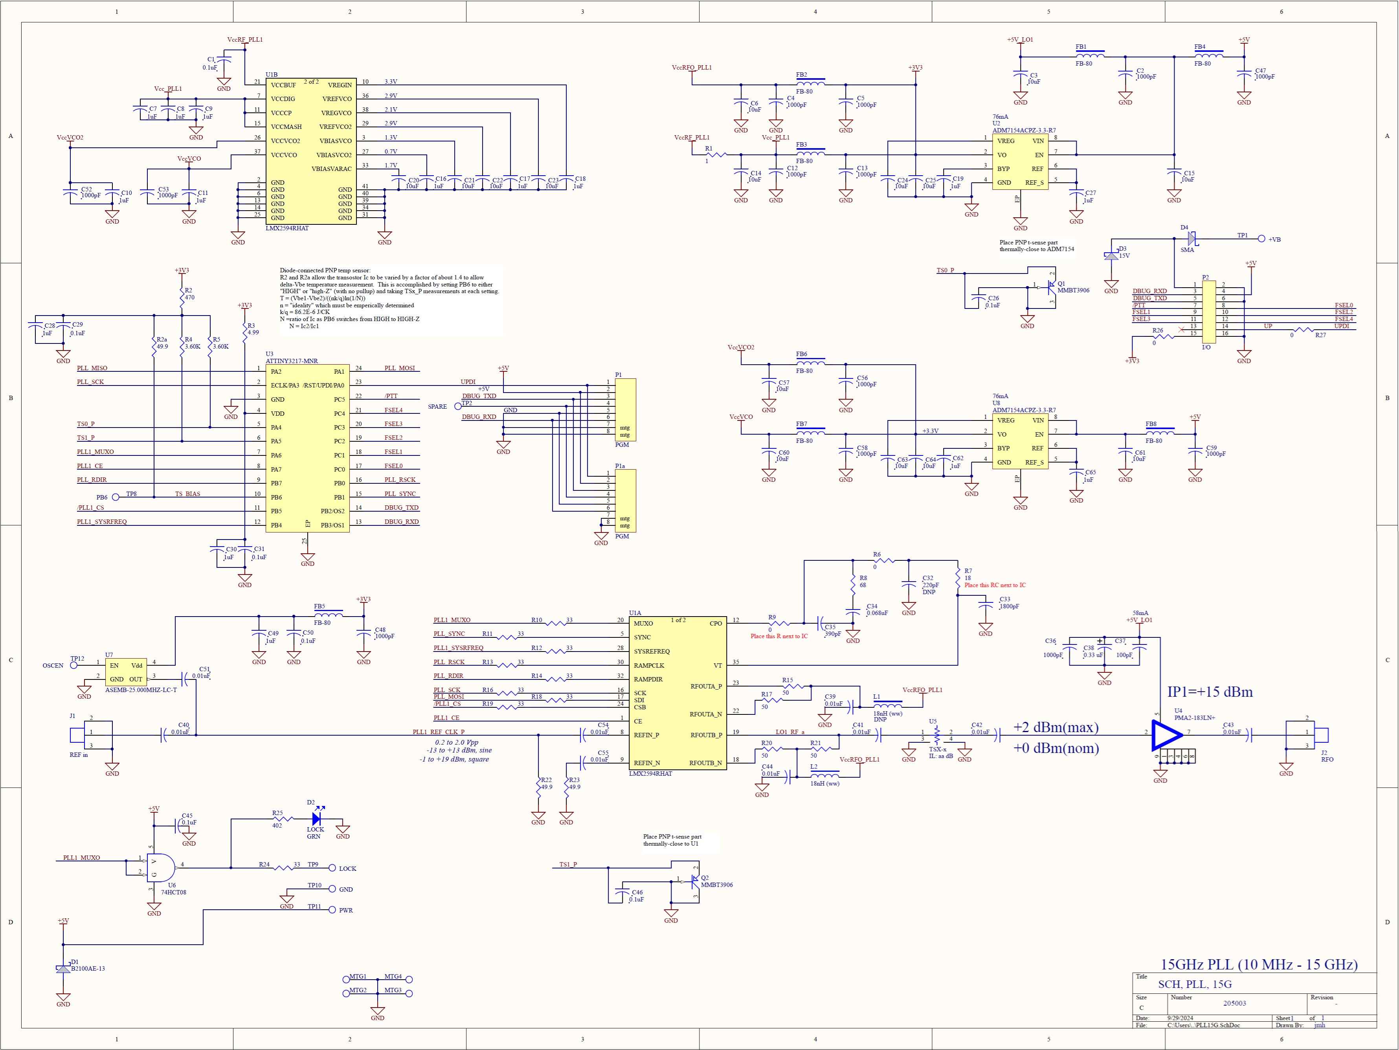
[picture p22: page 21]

© Joseph M. Haas, 03/30/2025, all rights reserved | 21 | Artemis-I Operation – Rev-

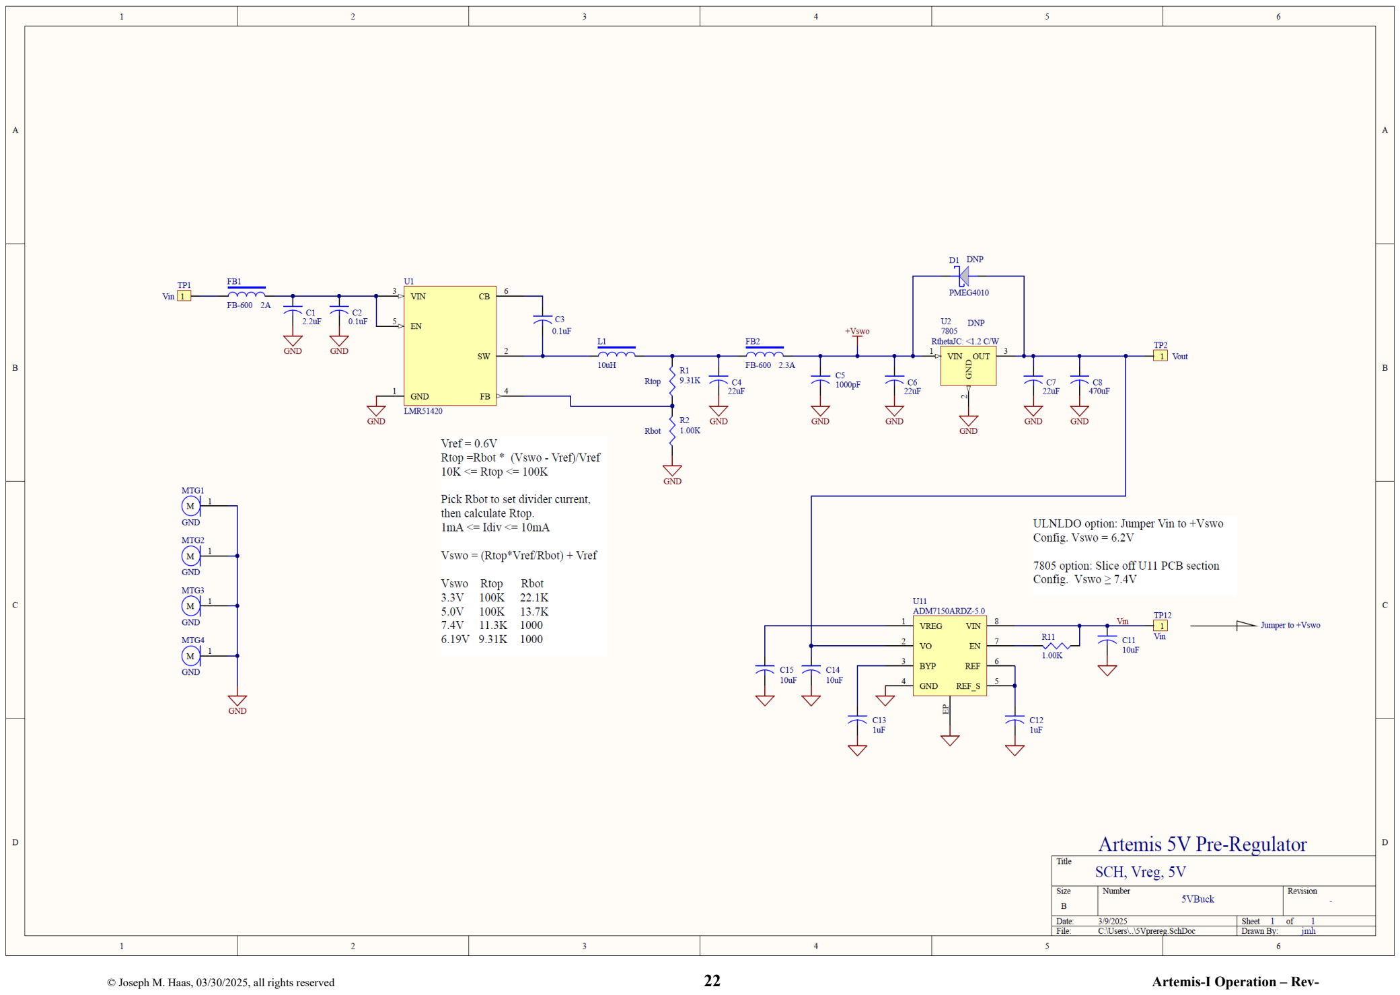
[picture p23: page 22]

© Joseph M. Haas, 03/30/2025, all rights reserved | 22 | Artemis-I Operation – Rev-

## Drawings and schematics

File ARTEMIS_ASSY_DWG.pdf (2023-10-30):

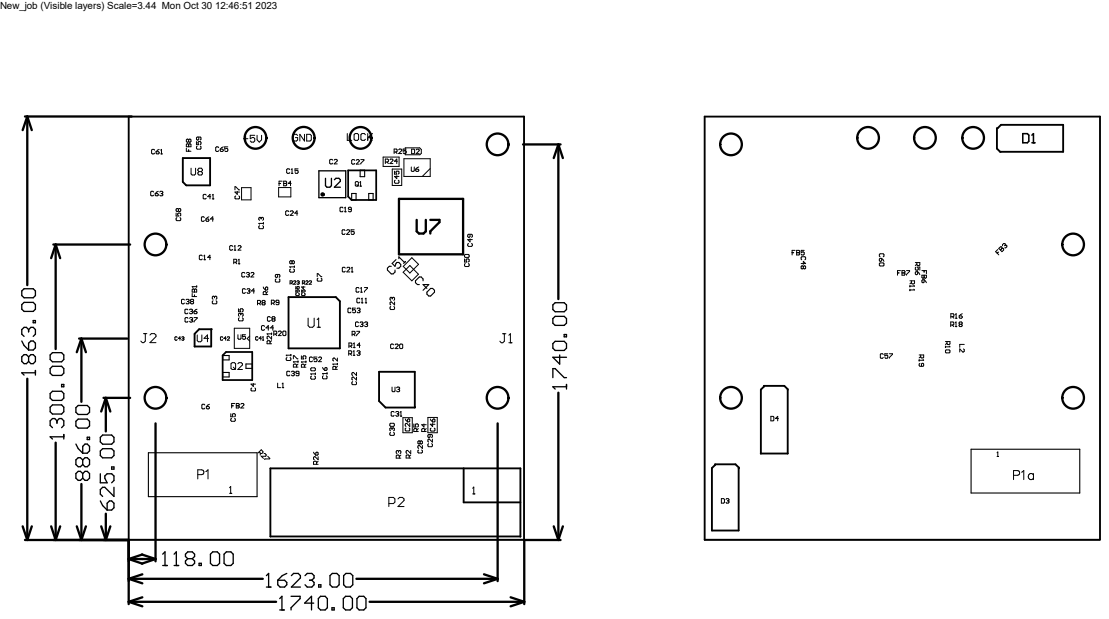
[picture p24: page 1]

New_job (Visible layers) Scale=3.44 Mon Oct 30 12:46:51 2023

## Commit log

2023-10-09 Initial commit
    First PCB-FAB and MCU source code committed as a ZIP archive. Future in-process commits will be file-by-file to the "Artemis Source" folder.
2023-10-30 Rev0.1 commit
    Post 1st-light commit with both temp sensors functional, /PTT toggles nCE, and one channel is sent to PLL at power-on. UART works (115200, n81).
2023-10-30 Initial commit
    Costed BOM (per each board)
    [Artemis_BOM.xlsx]
2023-10-30 Update ArtemisSpecs.txt
    Corrected board dimensions
2023-10-30 Initial commit
    Artemis PCB HW files for CircuitStudio/Altium
2024-09-30 Initial commit
    File to extract LMX2594 data from TICSPro exports formatted for inclusion in the channels.c source file for the Artemis MCU project.
    [register_extract.xlsx]
2024-09-30 Initial Commit
    Artemis heatsink drill/mill template files
    [artemis_template.3mf, artemis_template.scad, artemis_template.stl]
2024-10-22 revA commit
    [register_extract.xlsx]
2025-03-29 V0.3 Commit
    Added FLASH commands, temp channel download, temperature sensor calibration, and minor bug-fixes
2025-03-29 V0.3 in-process commit
    FLASH channel updates, download channel to temp channel, temperature cal, minor bug fixes
2025-03-30 V1.0+ commit
    Added BOOTEND fuse error message and fuse programming steps.
